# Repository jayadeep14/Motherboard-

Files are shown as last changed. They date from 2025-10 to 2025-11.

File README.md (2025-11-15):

# Motherboard - aizeronix
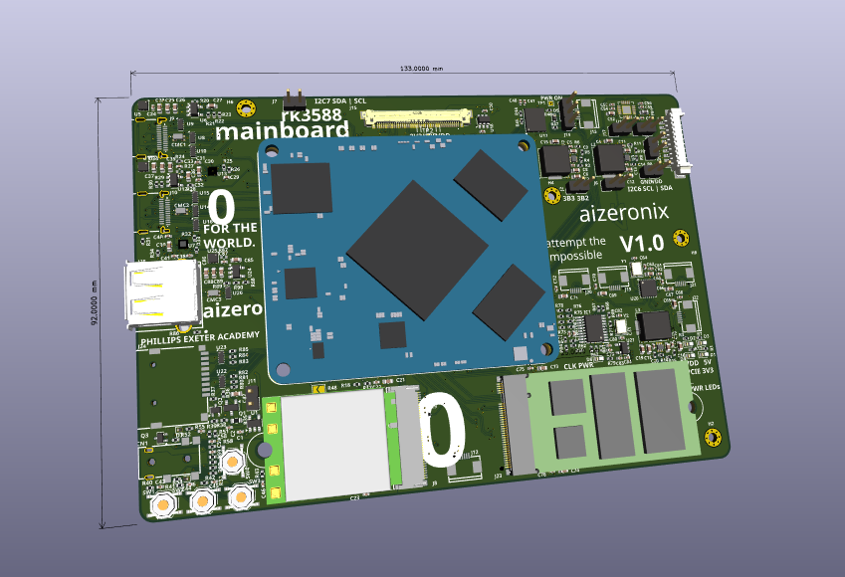
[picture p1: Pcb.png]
Pcb

This project focuses on the design and development of a custom motherboard using a rk3588. The goal is to create a compact, high-performance solution tailored for embedded systems and other specialized applications. The motherboard will feature a variety of interfaces for connectivity, expansion, and power management, all while leveraging Rockchip’s powerful processor architecture.  

Project Objectives

The project had both technical and design objectives:

Design a functional schematic of a custom RK3588 motherboard with essential peripherals and expansion options.

Develop a compact PCB layout, ensuring signal integrity, power stability, and thermal management.

Integrate various interfaces, including USB, Ethernet, MIPI camera inputs, HDMI outputs, and PCIe expansion.

Design a robust power management system, capable of handling multiple voltage rails efficiently.

Prototype and test the motherboard for functionality, stability, and performance

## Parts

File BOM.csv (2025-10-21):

JLCPCB BOM Tool - BOM Matching
BOM name：motherboard-JLCPCB Assembly Order.xlsx |  |  | Download Time：2025-10-21 23:37:49 |  |  |  | * Our matching results are updated in real-time, but stock and prices may change. If it's been over 24 hours, please re-match before placing your order.
PCB Assembled Qty：5 |  |  | Est. Total Price：95.7691
Your BOM |  |  |  |  | Matched Parts |  |  |  |  |  |  | Order Information
Top Designator | Bottom Designator | Comment | Footprint | JLCPCB Part # | Matches | Part # | Manufacturer | Footprint | Description | Category | Warning | JLCPCB Part # | Product link | Lib Type | Qty | Source | Total Price ($)
C30,C60,C65,C86,C28,C52,C42,C3,C16,C27,C4,C10,C37,C9,C67,C36,C71,C39,C15,C69,C85 |  | 10uF | C_0603_1608Metric |  | Unconfirmed | CL10A106KP8NNNC | Samsung Electro-Mechanics | 603 | 10V 10uF X5R ±10% 0603 Multilayer Ceramic Capacitors MLCC - SMD/SMT ROHS | Multilayer Ceramic Capacitors MLCC - SMD/SMT | 1.Multiple lines in the BOM have been matched to the same part. Please check if the matching is correct. ; | C19702 | https://jlcpcb.com/partdetail/20411-CL10A106KP8NNNC/C19702 | Basic | 145 | 145 JLCPCB | 0.812
C88,C26,C25,C35,C34,C89 |  | 10uF(C913517) | C_0603_1608Metric |  | Unconfirmed | CL10A106KP8NNNC | Samsung Electro-Mechanics | 603 | 10V 10uF X5R ±10% 0603 Multilayer Ceramic Capacitors MLCC - SMD/SMT ROHS | Multilayer Ceramic Capacitors MLCC - SMD/SMT | 1.Multiple lines in the BOM have been matched to the same part. Please check if the matching is correct. ; | C19702 | https://jlcpcb.com/partdetail/20411-CL10A106KP8NNNC/C19702 | Basic | 145 | 145 JLCPCB | 0.812
C33,C24,C87 |  | 100nF(+25V) | C_0402_1005Metric |  | Select by Customer | 0402B104K250NT | FH (Guangdong Fenghua Advanced Tech) | 402 | 100nF 25V X7R ±10% 0402 Multilayer Ceramic Capacitors MLCC - SMD/SMT ROHS | Multilayer Ceramic Capacitors MLCC - SMD/SMT |  | C56392 | https://jlcpcb.com/partdetail/57421-0402B104K250NT/C56392 | Extended | 27 | 27 JLCPCB | 0.0324
C41,C40,C32,C31 |  | 220pF | C_0402_1005Metric |  | Select by System | CL02B221KP2NNNC | Samsung Electro-Mechanics | 1005 | 10V 220pF X7R ±10% 01005 Multilayer Ceramic Capacitors MLCC - SMD/SMT ROHS | Multilayer Ceramic Capacitors MLCC - SMD/SMT |  | C514578 | https://jlcpcb.com/partdetail/530300-CL02B221KP2NNNC/C514578 | Extended | 40 | 40 JLCPCB | 0.252
C43,C46,C44,C45 |  | 1nF | C_0402_1005Metric |  | Select by System | GRM022R71C102KE14D | Murata Electronics | 1005 | 16V 1nF ±10% 01005 Multilayer Ceramic Capacitors MLCC - SMD/SMT ROHS | Multilayer Ceramic Capacitors MLCC - SMD/SMT |  | C907725 | https://jlcpcb.com/partdetail/973775-GRM022R71C102KE14D/C907725 | Extended | 40 | 40 JLCPCB | 0.264
C51,C68,C76,C70,C72,C66,C23,C61,C59,C58,C47 |  | 0.1uF | C_0402_1005Metric |  | Unconfirmed | GRM022R60J104KE15D | Murata Electronics | 1005 | 100nF 6.3V X5R ±10% 01005 Multilayer Ceramic Capacitors MLCC - SMD/SMT ROHS | Multilayer Ceramic Capacitors MLCC - SMD/SMT | 1.The comment (GRM022R60J104KE15D) of this part does not match the one (0.1uF) provided in your BOM. Please confirm; 2.Multiple lines in the BOM have been matched to the same part. Please check if the matching is correct. ; | C161362 | https://jlcpcb.com/partdetail/172743-GRM022R60J104KE15D/C161362 | Extended | 120 | 120 JLCPCB | 0.312
C80,C11,C14,C29,C38,C8,C78,C20,C5,C17 |  | 100nF | C_0402_1005Metric |  | Unconfirmed | GRM022R60J104KE15D | Murata Electronics | 1005 | 100nF 6.3V X5R ±10% 01005 Multilayer Ceramic Capacitors MLCC - SMD/SMT ROHS | Multilayer Ceramic Capacitors MLCC - SMD/SMT | 1.Multiple lines in the BOM have been matched to the same part. Please check if the matching is correct. ; | C161362 | https://jlcpcb.com/partdetail/172743-GRM022R60J104KE15D/C161362 | Extended | 120 | 120 JLCPCB | 0.312
C64,C63,C81,C82 |  | 15pF | C_0402_1005Metric |  | Select by Customer | 0402CG150J500NT | FH (Guangdong Fenghua Advanced Tech) | 402 | 15pF 50V C0G ±5% 0402 Multilayer Ceramic Capacitors MLCC - SMD/SMT ROHS | Multilayer Ceramic Capacitors MLCC - SMD/SMT |  | C1548 | https://jlcpcb.com/partdetail/1900-0402CG150J500NT/C1548 | Basic | 30 | 30 JLCPCB | 0.03
C74,C6,C13,C21,C7,C18,C19,C12,C73 |  | 22uF | C_0603_1608Metric |  | Select by System | CL10A226MQ8NRNC | Samsung Electro-Mechanics | 603 | 22uF 6.3V X5R ±20% 0603 Multilayer Ceramic Capacitors MLCC - SMD/SMT ROHS | Multilayer Ceramic Capacitors MLCC - SMD/SMT |  | C59461 | https://jlcpcb.com/partdetail/60514-CL10A226MQ8NRNC/C59461 | Basic | 55 | 55 JLCPCB | 0.4785
C84,C83,C48,C49,C53,C2,C57,C77,C22,C79,C50,C75,C62,C56,C1,C55,C54 |  | 1uF | C_0402_1005Metric |  | Select by Customer | GRM155R60J105KE19D | Murata Electronics | 402 | 1uF 6.3V X5R ±10% 0402 Multilayer Ceramic Capacitors MLCC - SMD/SMT ROHS | Multilayer Ceramic Capacitors MLCC - SMD/SMT |  | C15684 | https://jlcpcb.com/partdetail/MurataElectronics-GRM155R60J105KE19D/C15684 | Extended | 95 | 95 JLCPCB | 0.266
CMC3,CMC2,CMC1 |  | ACM2012 | FIL_ACM2012-900-2P-T001 |  | Select by System | ACM2012-121-2P-T002 | TDK | SMD-4P | -40℃~+85℃ 120Ω@100MHz 2 220mΩ 370mA 50V SMD-4P Common Mode Filters ROHS | Common Mode Filters |  | C76571 | https://jlcpcb.com/partdetail/TDK-ACM2012_121_2PT002/C76571 | Extended | 17 | 17 JLCPCB | 1.666
CN1 |  | PJ-332A-6A(3.5mmJack) | AUDIO-SMD_PJ-332A-6A |  | Unconfirmed | PJ-332A-6A | Korean Hroparts Elec | SMD | -25℃~+80℃ 1A 3.5mm Headphone Jack 30V SMD Audio Connectors ROHS | Audio Connectors (Headphones) | 1.The comment (PJ-332A-6A) of this part does not match the one (PJ-332A-6A(3.5mmJack)) provided in your BOM. Please confirm; | C2848643 | https://jlcpcb.com/partdetail/Korean_HropartsElec-PJ_332A6A/C2848643 | Extended | 5 | 5 JLCPCB | 1.186
D1 |  | +3.3VLED | LED_0603_1608Metric |  | Unconfirmed | KT-0603R | Hubei KENTO Elec | 603 | -40℃~+85℃ 120° 2.4V 20mA 300mcd 40mW 615nm~630nm 645nm Red Water Clear 0603 LED Indication - Discrete ROHS | LED Indication - Discrete | 1.The comment (KT-0603R) of this part does not match the one (+3.3VLED) provided in your BOM. Please confirm; 2.Multiple lines in the BOM have been matched to the same part. Please check if the matching is correct. ; | C2286 | https://jlcpcb.com/partdetail/Hubei_KENTOElec-KT0603R/C2286 | Basic | 35 | 35 JLCPCB | 0.196
D2 |  | VDDLED | LED_0603_1608Metric |  | Unconfirmed | KT-0603R | Hubei KENTO Elec | 603 | -40℃~+85℃ 120° 2.4V 20mA 300mcd 40mW 615nm~630nm 645nm Red Water Clear 0603 LED Indication - Discrete ROHS | LED Indication - Discrete | 1.The comment (KT-0603R) of this part does not match the one (VDDLED) provided in your BOM. Please confirm; 2.Multiple lines in the BOM have been matched to the same part. Please check if the matching is correct. ; | C2286 | https://jlcpcb.com/partdetail/Hubei_KENTOElec-KT0603R/C2286 | Basic | 35 | 35 JLCPCB | 0.196
D3 |  | +5VLED | LED_0603_1608Metric |  | Unconfirmed | KT-0603R | Hubei KENTO Elec | 603 | -40℃~+85℃ 120° 2.4V 20mA 300mcd 40mW 615nm~630nm 645nm Red Water Clear 0603 LED Indication - Discrete ROHS | LED Indication - Discrete | 1.The comment (KT-0603R) of this part does not match the one (+5VLED) provided in your BOM. Please confirm; 2.Multiple lines in the BOM have been matched to the same part. Please check if the matching is correct. ; | C2286 | https://jlcpcb.com/partdetail/Hubei_KENTOElec-KT0603R/C2286 | Basic | 35 | 35 JLCPCB | 0.196
D4 |  | PCIELED | LED_0603_1608Metric |  | Unconfirmed | KT-0603R | Hubei KENTO Elec | 603 | -40℃~+85℃ 120° 2.4V 20mA 300mcd 40mW 615nm~630nm 645nm Red Water Clear 0603 LED Indication - Discrete ROHS | LED Indication - Discrete | 1.The comment (KT-0603R) of this part does not match the one (PCIELED) provided in your BOM. Please confirm; 2.Multiple lines in the BOM have been matched to the same part. Please check if the matching is correct. ; | C2286 | https://jlcpcb.com/partdetail/Hubei_KENTOElec-KT0603R/C2286 | Basic | 35 | 35 JLCPCB | 0.196
D8 |  | PI6CLED | LED_0603_1608Metric |  | Unconfirmed | KT-0603R | Hubei KENTO Elec | 603 | -40℃~+85℃ 120° 2.4V 20mA 300mcd 40mW 615nm~630nm 645nm Red Water Clear 0603 LED Indication - Discrete ROHS | LED Indication - Discrete | 1.The comment (KT-0603R) of this part does not match the one (PI6CLED) provided in your BOM. Please confirm; 2.Multiple lines in the BOM have been matched to the same part. Please check if the matching is correct. ; | C2286 | https://jlcpcb.com/partdetail/Hubei_KENTOElec-KT0603R/C2286 | Basic | 35 | 35 JLCPCB | 0.196
D5 |  | LRB521S-30T1G | D_SOD-523 |  | Select by System | LRB521S-30T1G | LRC | SOD-523 | -40℃~+125℃ 1A 200mA 30V 30uA 500mV SOD-523 Schottky Diodes ROHS | Schottky Diodes |  | C83681 | https://jlcpcb.com/partdetail/LRC-LRB521S30T1G/C83681 | Extended | 20 | 20 JLCPCB | 0.284
D6,D7 |  | LESD8D5.0CB1T5G | D_SOD-882 |  | Select by System | LESD8D5.0CB1T5G | LRC | SOD-882 | -40℃~+150℃ 10A@8/20us 20pF 500nA 5V 85W@8/20us 8V 9V ESD SOD-882 ESD and Surge Protection (TVS/ESD) ROHS | ESD And Surge Protection (TVS/ESD) |  | C2936709 | https://jlcpcb.com/partdetail/LRC-LESD8D50CB1T5G/C2936709 | Extended | 20 | 20 JLCPCB | 0.176
FB1 |  | GZ1608D601TF | L_0603_1608Metric |  | Select by System | GZ1608D601TF | Sunlord | 603 | -55℃~+125℃ 1 200mA 450mΩ 600Ω@100MHz ±25% 0603 Ferrite Beads ROHS | Ferrite Beads |  | C1002 | https://jlcpcb.com/partdetail/Sunlord-GZ1608D601TF/C1002 | Basic | 20 | 20 JLCPCB | 0.132
H3,H5,H1,H7 |  | Hirose | Blank |  | Select by Customer | DF40C-100DS-0.4V(51) | HRS(Hirose) | SMD,P=0.4mm | -35℃~+85℃ 0.4mm 2 300mA Gold Surface Mount,Vertical SMD,P=0.4mm Board-to-Board and Backplane Connector ROHS | Board-To-Board And Backplane Connector |  | C597931 | https://jlcpcb.com/partdetail/HRS_Hirose-DF40C_100DS_0_4V_51/C597931 | Extended | 20 | 20 JLCPCB | 14.49
IC1 |  | PI6C557-05BLE | SOP65P640X120-20N |  | Select by System | PI6C557-05BLE | Diodes Incorporated | TSSOP-20 | -40℃~+85℃ 200MHz 3.135V~3.465V 4 TSSOP-20 Clock Generators, PLLs, Frequency Synthesizers ROHS | Clock Generators, PLLs, Frequency Synthesizers |  | C212303 | https://jlcpcb.com/partdetail/DiodesIncorporated-PI6C55705BLE/C212303 | Extended | 5 | 5 JLCPCB | 7.545
J4 |  | BATTERYIN | Molex_PicoBlade_53261-1071_1x10-1MP_P1.25mm_Horizontal |  | Select by Customer | 532611071 | MOLEX | SMD,P=1.25mm,卧贴 | -40℃~+105℃ 1 1.25mm 10 10P 125V 17.65mm 1A 1x10P 3.4mm 5.2mm Auxiliary Solder Pin Glass-Fiber Reinforced PA Phosphor Bronze PicoBlade(MX 1.25) Surface Mount, Right Angle Tin UL94V-0 White SMD,P=1.25mm,Surface Mount，Right Angle Wire To Board Connector ROHS | Wire To Board Connector |  | C564042 | https://jlcpcb.com/partdetail/MOLEX-532611071/C564042 | Extended | 5 | 5 JLCPCB | 1.14
J8 |  | Bus_M.2_Socket_E | CONN-SMD_APCI0147-P001A |  | Unconfirmed | APCI0147-P001A | LOTES | SMD,P=0.5mm,卧贴 | 2.05mm 67P Female M.2-E Key Surface Mount, Right Angle with locating pin SMD,P=0.5mm,Surface Mount，Right Angle Hard Disk Connector (SAS/SATA/M.2) ROHS | Edgeboard Connectors | 1.The comment (APCI0147-P001A) of this part does not match the one (Bus_M.2_Socket_E) provided in your BOM. Please confirm; | C841646 | https://jlcpcb.com/partdetail/LOTES-APCI0147P001A/C841646 | Extended | 5 | 5 JLCPCB | 3.015
J9 |  | OuterUSB-C | USB-C-SMD_TYPE-C-24P-QT |  | Unconfirmed | TYPE-C 24P QT | SHOU HAN | SMD | -30℃~+80℃ 1 10,000 Cycles 24P 3A Black Female Surface Mount, Right Angle Type-C USB 3.1 SMD USB Connectors ROHS | USB Connectors | 1.The comment (TYPE-C 24P QT) of this part does not match the one (OuterUSB-C) provided in your BOM. Please confirm; 2.Multiple lines in the BOM have been matched to the same part. Please check if the matching is correct. ; | C2681555 | https://jlcpcb.com/partdetail/SHOUHAN-TYPE_C_24PQT/C2681555 | Extended | 10 | 10 JLCPCB | 4.725
J10 |  | USB_C_Receptacle | USB-C-SMD_TYPE-C-24P-QT |  | Unconfirmed | TYPE-C 24P QT | SHOU HAN | SMD | -30℃~+80℃ 1 10,000 Cycles 24P 3A Black Female Surface Mount, Right Angle Type-C USB 3.1 SMD USB Connectors ROHS | USB Connectors | 1.The comment (TYPE-C 24P QT) of this part does not match the one (USB_C_Receptacle) provided in your BOM. Please confirm; 2.Multiple lines in the BOM have been matched to the same part. Please check if the matching is correct. ; | C2681555 | https://jlcpcb.com/partdetail/SHOUHAN-TYPE_C_24PQT/C2681555 | Extended | 10 | 10 JLCPCB | 4.725
J12 |  | HALLSWITCH | FPC-SMD_6P-P0.50_XUNPU_FPC-05F-6PH20 |  | Unconfirmed | FPC-05F-6PH20 | XUNPU | SMD,P=0.5mm,卧贴 | -25℃~+85℃ 0.3mm 0.5mm 2mm 500mA 50V 6P Bottom Contact Hinged Lid Phosphor Bronze Surface Mount, Right Angle Tin SMD,P=0.5mm,Surface Mount，Right Angle FFC, FPC (Flat Flexible) Connector Assemblies ROHS | FFC, FPC (Flat Flexible) Connector Assemblies | 1.The comment (FPC-05F-6PH20) of this part does not match the one (HALLSWITCH) provided in your BOM. Please confirm; 2.Multiple lines in the BOM have been matched to the same part. Please check if the matching is correct. ; | C2856796 | https://jlcpcb.com/partdetail/XUNPU-FPC_05F6PH20/C2856796 | Extended | 32 | 32 JLCPCB | 2.6368
J13 |  | SYSTEM | FPC-SMD_6P-P0.50_XUNPU_FPC-05F-6PH20 |  | Unconfirmed | FPC-05F-6PH20 | XUNPU | SMD,P=0.5mm,卧贴 | -25℃~+85℃ 0.3mm 0.5mm 2mm 500mA 50V 6P Bottom Contact Hinged Lid Phosphor Bronze Surface Mount, Right Angle Tin SMD,P=0.5mm,Surface Mount，Right Angle FFC, FPC (Flat Flexible) Connector Assemblies ROHS | FFC, FPC (Flat Flexible) Connector Assemblies | 1.The comment (FPC-05F-6PH20) of this part does not match the one (SYSTEM) provided in your BOM. Please confirm; 2.Multiple lines in the BOM have been matched to the same part. Please check if the matching is correct. ; | C2856796 | https://jlcpcb.com/partdetail/XUNPU-FPC_05F6PH20/C2856796 | Extended | 32 | 32 JLCPCB | 2.6368
J20,J19,J21,J22 |  | USB | FPC-SMD_6P-P0.50_XUNPU_FPC-05F-6PH20 |  | Unconfirmed | FPC-05F-6PH20 | XUNPU | SMD,P=0.5mm,卧贴 | -25℃~+85℃ 0.3mm 0.5mm 2mm 500mA 50V 6P Bottom Contact Hinged Lid Phosphor Bronze Surface Mount, Right Angle Tin SMD,P=0.5mm,Surface Mount，Right Angle FFC, FPC (Flat Flexible) Connector Assemblies ROHS | FFC, FPC (Flat Flexible) Connector Assemblies | 1.The comment (FPC-05F-6PH20) of this part does not match the one (USB) provided in your BOM. Please confirm; 2.Multiple lines in the BOM have been matched to the same part. Please check if the matching is correct. ; | C2856796 | https://jlcpcb.com/partdetail/XUNPU-FPC_05F6PH20/C2856796 | Extended | 32 | 32 JLCPCB | 2.6368
J23 |  | Bus_M.2_Socket_M | CONN-SMD_AS0BC21-S30BM-7H |  | Unconfirmed | AS0BC21-S30BM-7H | FOXCONN | SMD,P=0.5mm,卧贴 | -40℃~+80℃ 67P Female M.2-M Key Surface Mount, Right Angle with locating pin SMD,P=0.5mm,Surface Mount，Right Angle Hard Disk Connector (SAS/SATA/M.2) ROHS | Edgeboard Connectors | 1.The comment (AS0BC21-S30BM-7H) of this part does not match the one (Bus_M.2_Socket_M) provided in your BOM. Please confirm; | C2832351 | https://jlcpcb.com/partdetail/FOXCONN-AS0BC21_S30BM7H/C2832351 | Extended | 5 | 5 JLCPCB | 1.6465
J24 |  | Micro_SD_Card_Det1 | TF-SMD_TF-CARD-H1.8 |  | Unconfirmed | TF-CARD H1.8 | SHOU HAN | SMD | -40℃~+70℃ 1.8mm Connector and Ejector MicroSD Card (TF Card) Push-Push SMD SD Card / Memory Card Connector ROHS | SD Card / Memory Card Connector | 1.The comment (TF-CARD H1.8) of this part does not match the one (Micro_SD_Card_Det1) provided in your BOM. Please confirm; | C7529389 | https://jlcpcb.com/partdetail/SHOUHAN-TF_CARD_H18/C7529389 | Extended | 5 | 5 JLCPCB | 0.2845
J25 |  | USB-231-ARY | USB-A-TH_USB-231-ARY |  | Select by System | USB-231-ARY | XUNPU | 弯插 | -20℃~+70℃ 1 1.5A 14.2mm 30V 4P Female Right Angle Type-A USB 2.0 White Push-Pull USB Connectors ROHS | USB Connectors |  | C720525 | https://jlcpcb.com/partdetail/XUNPU-USB_231ARY/C720525 | Extended | 5 | 5 JLCPCB | 0.6685
L1,L3 |  | MWSA0603S-3R3MT | L_Sunlord_MWSA0603S |  | Select by System | MWSA0603S-3R3MT | Sunlord | SMD,7x6.6mm | 22mΩ 3.3uH 8.5A 9.5A ±20% SMD,7x6.6mm Power Inductors ROHS | Power Inductors |  | C408446 | https://jlcpcb.com/partdetail/Sunlord-MWSA0603S3R3MT/C408446 | Extended | 11 | 11 JLCPCB | 1.2474
L2 |  | FXL0630-4R7-M | L_Sunlord_MWSA0603S |  | Select by System | FXL0630-4R7-M | cjiang (Changjiang Microelectronics Tech) | SMD,7x6.6mm | 33mΩ 4.7uH 6A 9A Molded Inductor ±20% SMD,7x6.6mm Power Inductors ROHS | Power Inductors |  | C167220 | https://jlcpcb.com/partdetail/178603-FXL0630_4R7M/C167220 | Extended | 6 | 6 JLCPCB | 0.5196
Q1 |  | AO3415A | SOT-23 |  | Select by System | AO3415A | UMW(Youtai Semiconductor Co., Ltd.) | SOT-23 | -55℃~+150℃ 1 P-Channel 1.45nF 160pF 17.2nC@4.5V 205pF 20V 350mW 36mΩ@4.5V 4A 560mV@250uA N-Channel SOT-23 MOSFETs ROHS | MOSFETs |  | C347479 | https://jlcpcb.com/partdetail/324139-AO3415A/C347479 | Extended | 9 | 9 JLCPCB | 0.3321
Q3,Q2 |  | 2SK3018W | SOT-323_SC-70 |  | Select by System | 2SK3018W | TWGMC | SOT-323 | -55℃~+150℃ 1 N-Channel 1.5V 100mA 13pF 13Ω@2.5V,1mA 200mW 30V 4pF 9pF SOT-323 MOSFETs ROHS | MOSFETs |  | C5273793 | https://jlcpcb.com/partdetail/TWGMC-2SK3018W/C5273793 | Extended | 15 | 15 JLCPCB | 0.243
R5,R15 |  | 510k | R_0402_1005Metric |  | Unconfirmed | 0105WHJ0514TDE | UNI-ROYAL(Uniroyal Elec) | 1005 | -55℃~+125℃ 15V 31.25mW 510kΩ Thick Film Resistor ±200ppm/℃ ±5% 01005 Chip Resistor - Surface Mount ROHS | Chip Resistor - Surface Mount | 1.The comment (0105WHJ0514TDE) of this part does not match the one (510k) provided in your BOM. Please confirm; | C270295 | https://jlcpcb.com/partdetail/259825-0105WHJ0514TDE/C270295 | Extended | 40 | 40 JLCPCB | 0.184
R9 |  | 220k | R_0402_1005Metric |  | Unconfirmed | 0105WHF2203TDE | UNI-ROYAL(Uniroyal Elec) | 1005 | -55℃~+125℃ 15V 220kΩ 31.25mW Thick Film Resistor ±1% ±200ppm/℃ 01005 Chip Resistor - Surface Mount ROHS | Chip Resistor - Surface Mount | 1.The comment (0105WHF2203TDE) of this part does not match the one (220k) provided in your BOM. Please confirm; | C473646 | https://jlcpcb.com/partdetail/480039-0105WHF2203TDE/C473646 | Extended | 40 | 40 JLCPCB | 0.264
R10 |  | 330k | R_0402_1005Metric |  | Unconfirmed | 0105WHF3303TDE | UNI-ROYAL(Uniroyal Elec) | 1005 | -55℃~+125℃ 15V 31.25mW 330kΩ Thick Film Resistor ±1% ±200ppm/℃ 01005 Chip Resistor - Surface Mount ROHS | Chip Resistor - Surface Mount | 1.The comment (0105WHF3303TDE) of this part does not match the one (330k) provided in your BOM. Please confirm; | C778410 | https://jlcpcb.com/partdetail/827054-0105WHF3303TDE/C778410 | Extended | 20 | 20 JLCPCB | 0.06
R14,R4 |  | 49.9k | R_0402_1005Metric |  | Unconfirmed | RC0100FR-0749K9L | YAGEO | 1005 | -55℃~+125℃ 15V 31.25mW 49.9kΩ Thick Film Resistor ±1% ±200ppm/℃ 01005 Chip Resistor - Surface Mount ROHS | Chip Resistor - Surface Mount | 1.The comment (RC0100FR-0749K9L) of this part does not match the one (49.9k) provided in your BOM. Please confirm; | C850275 | https://jlcpcb.com/partdetail/YAGEO-RC0100FR0749K9L/C850275 | Extended | 40 | 40 JLCPCB | 0.108
R28,R88,R21,R51 |  | 100k | R_0402_1005Metric |  | Unconfirmed | RC0100FR-07100KL | YAGEO | 1005 | -55℃~+125℃ 100kΩ 15V 31.25mW Thick Film Resistor ±1% ±200ppm/℃ 01005 Chip Resistor - Surface Mount ROHS | Chip Resistor - Surface Mount | 1.The comment (RC0100FR-07100KL) of this part does not match the one (100k) provided in your BOM. Please confirm; | C723496 | https://jlcpcb.com/partdetail/YAGEO-RC0100FR07100KL/C723496 | Extended | 40 | 40 JLCPCB | 0.108
R31,R86,R24 |  | 1M | R_0402_1005Metric |  | Unconfirmed | MCR004YZPJ105 | ROHM Semicon | 1005 | -55℃~+125℃ 15V 1MΩ 31mW Thick Film Resistor ±250ppm/℃ ±5% 01005 Chip Resistor - Surface Mount ROHS | Chip Resistor - Surface Mount | 1.The comment (MCR004YZPJ105) of this part does not match the one (1M) provided in your BOM. Please confirm; | C307987 | https://jlcpcb.com/partdetail/ROHMSemicon-MCR004YZPJ105/C307987 | Extended | 40 | 40 JLCPCB | 0.252
R33,R25,R32,R26,R50,R19 |  | 2.2k | R_0402_1005Metric |  | Unconfirmed | RC0100JR-072K2L | YAGEO | 1005 | -55℃~+125℃ 15V 2.2kΩ 31.25mW Thick Film Resistor ±200ppm/℃ ±5% 01005 Chip Resistor - Surface Mount ROHS | Chip Resistor - Surface Mount | 1.The comment (RC0100JR-072K2L) of this part does not match the one (2.2k) provided in your BOM. Please confirm; | C723377 | https://jlcpcb.com/partdetail/YAGEO-RC0100JR072K2L/C723377 | Extended | 45 | 45 JLCPCB | 0.099
R35 |  | 2.2R | R_0603_1608Metric |  | Unconfirmed | 0603WAF220KT5E | UNI-ROYAL(Uniroyal Elec) | 603 | -55℃~+155℃ 100mW 2.2Ω 75V Thick Film Resistor ±1% ±400ppm/℃ 0603 Chip Resistor - Surface Mount ROHS | Chip Resistor - Surface Mount | 1.The comment (0603WAF220KT5E) of this part does not match the one (2.2R) provided in your BOM. Please confirm; | C22939 | https://jlcpcb.com/partdetail/23666-0603WAF220KT5E/C22939 | Basic | 20 | 20 JLCPCB | 0.032
R37 |  | 1k | R_0402_1005Metric |  | Unconfirmed | 0105WHJ0102TDE | UNI-ROYAL(Uniroyal Elec) | 1005 | -55℃~+125℃ 15V 1kΩ 31.25mW Thick Film Resistor ±200ppm/℃ ±5% 01005 Chip Resistor - Surface Mount ROHS | Chip Resistor - Surface Mount | 1.The comment (0105WHJ0102TDE) of this part does not match the one (1k) provided in your BOM. Please confirm; | C407788 | https://jlcpcb.com/partdetail/396345-0105WHJ0102TDE/C407788 | Extended | 40 | 40 JLCPCB | 0.216
R39,R43,R41,R40,R71,R42 |  | 100R | R_0402_1005Metric |  | Unconfirmed | 0105WHJ0101TDE | UNI-ROYAL(Uniroyal Elec) | 1005 | -55℃~+125℃ 100Ω 15V 31.25mW Thick Film Resistor ±400ppm/℃ ±5% 01005 Chip Resistor - Surface Mount ROHS | Chip Resistor - Surface Mount | 1.The comment (0105WHJ0101TDE) of this part does not match the one (100R) provided in your BOM. Please confirm; | C270299 | https://jlcpcb.com/partdetail/259829-0105WHJ0101TDE/C270299 | Extended | 45 | 45 JLCPCB | 0.2385
R52,R57,R7,R8,R1,R12,R67,R16,R44,R13,R46,R45,R68,R2,R6,R56,R38,R34 |  | 10k | R_0402_1005Metric |  | Unconfirmed | 0105WHJ0103TDE | UNI-ROYAL(Uniroyal Elec) | 1005 | -55℃~+125℃ 10kΩ 15V 31.25mW Thick Film Resistor ±200ppm/℃ ±5% 01005 Chip Resistor - Surface Mount ROHS | Chip Resistor - Surface Mount | 1.The comment (0105WHJ0103TDE) of this part does not match the one (10k) provided in your BOM. Please confirm; | C407787 | https://jlcpcb.com/partdetail/396344-0105WHJ0103TDE/C407787 | Extended | 105 | 105 JLCPCB | 0.567
R63,R17,R55,R61,R54,R87,R20,R27,R53,R18 |  | 0R | R_0402_1005Metric |  | Unconfirmed | RC0100FR-070RL | YAGEO | 1005 | -55℃~+125℃ 0Ω 15V 31.25mW Thick Film Resistor ±1% 01005 Chip Resistor - Surface Mount ROHS | Chip Resistor - Surface Mount | 1.The comment (RC0100FR-070RL) of this part does not match the one (0R) provided in your BOM. Please confirm; | C2936587 | https://jlcpcb.com/partdetail/YAGEO-RC0100FR070RL/C2936587 | Extended | 65 | 65 JLCPCB | 0.2535
R66 |  | 4.7k | R_0402_1005Metric |  | Unconfirmed | 0105WHJ0472TDE | UNI-ROYAL(Uniroyal Elec) | 1005 | -55℃~+125℃ 15V 31.25mW 4.7kΩ Thick Film Resistor ±200ppm/℃ ±5% 01005 Chip Resistor - Surface Mount ROHS | Chip Resistor - Surface Mount | 1.The comment (0105WHJ0472TDE) of this part does not match the one (4.7k) provided in your BOM. Please confirm; | C423829 | https://jlcpcb.com/partdetail/416779-0105WHJ0472TDE/C423829 | Extended | 40 | 40 JLCPCB | 0.228
R69,R36 |  | 470R | R_0402_1005Metric |  | Select by Customer | 0402WGF4700TCE | UNI-ROYAL(Uniroyal Elec) | 402 | -55℃~+155℃ 470Ω 50V 62.5mW Thick Film Resistor ±1% ±100ppm/℃ 0402 Chip Resistor - Surface Mount ROHS | Chip Resistor - Surface Mount | 1.The comment (0402WGF4700TCE) of this part does not match the one (470R) provided in your BOM. Please confirm; | C25117 | https://jlcpcb.com/partdetail/25860-0402WGF4700TCE/C25117 | Basic | 20 | 20 JLCPCB | 0.012
R72,R85,R62,R60,R76,R58,R80,R82,R81,R84,R70,R59,R83,R75,R47 |  | 33R | R_0402_1005Metric |  | Select by Customer | 0402WGF330JTCE | UNI-ROYAL(Uniroyal Elec) | 402 | -55℃~+155℃ 33Ω 50V 62.5mW Thick Film Resistor ±1% ±100ppm/℃ 0402 Chip Resistor - Surface Mount ROHS | Chip Resistor - Surface Mount | 1.The comment (0402WGF330JTCE) of this part does not match the one (33R) provided in your BOM. Please confirm; | C25105 | https://jlcpcb.com/partdetail/25848-0402WGF330JTCE/C25105 | Basic | 85 | 85 JLCPCB | 0.051
R73,R64,R74,R77,R78,R65 |  | 49.9R | R_0402_1005Metric |  | Unconfirmed | 0105WHF499JTDE | UNI-ROYAL(Uniroyal Elec) | 1005 | -55℃~+125℃ 15V 31.25mW 49.9Ω Thick Film Resistor ±1% ±300ppm/℃ 01005 Chip Resistor - Surface Mount ROHS | Chip Resistor - Surface Mount | 1.The comment (0105WHF499JTDE) of this part does not match the one (49.9R) provided in your BOM. Please confirm; | C560373 | https://jlcpcb.com/partdetail/584835-0105WHF499JTDE/C560373 | Extended | 45 | 45 JLCPCB | 0.351
R79,R11,R3 |  | 33k | R_0402_1005Metric |  | Unconfirmed | 0105WHF3302TDE | UNI-ROYAL(Uniroyal Elec) | 1005 | -55℃~+125℃ 15V 31.25mW 33kΩ Thick Film Resistor ±1% ±200ppm/℃ 01005 Chip Resistor - Surface Mount ROHS | Chip Resistor - Surface Mount | 1.The comment (0105WHF3302TDE) of this part does not match the one (33k) provided in your BOM. Please confirm; | C560356 | https://jlcpcb.com/partdetail/584818-0105WHF3302TDE/C560356 | Extended | 40 | 40 JLCPCB | 0.26
R90,R89,R23,R29,R30,R22 |  | 6.8k | R_0402_1005Metric |  | Select by Customer | 0402WGF6801TCE | UNI-ROYAL(Uniroyal Elec) | 402 | -55℃~+155℃ 50V 6.8kΩ 62.5mW Thick Film Resistor ±1% ±100ppm/℃ 0402 Chip Resistor - Surface Mount ROHS | Chip Resistor - Surface Mount | 1.The comment (0402WGF6801TCE) of this part does not match the one (6.8k) provided in your BOM. Please confirm; | C25917 | https://jlcpcb.com/partdetail/26660-0402WGF6801TCE/C25917 | Extended | 40 | 40 JLCPCB | 0.024
SW1 |  | PWR | SW_Push_1P1T_XKB_TS-1187A |  | Select by Customer | TS-1187A-B-A-B | XKB Connection | SMD-4P,5.1x5.1mm | -30℃~+85℃ 1.5mm 1.6N 100,000 Cycles 12V 5.1mm 5.1mm 50mA Gold No Round Button SPST Surface Mount,Vertical Without Bracket SMD-4P,5.1x5.1mm Tactile Switches ROHS | Tactile Switches | 1.Multiple lines in the BOM have been matched to the same part. Please check if the matching is correct. ; | C318884 | https://jlcpcb.com/partdetail/XKBConnection-TS_1187A_B_AB/C318884 | Basic | 25 | 25 JLCPCB | 0.465
SW2 |  | RESET | SW_Push_1P1T_XKB_TS-1187A |  | Select by Customer | TS-1187A-B-A-B | XKB Connection | SMD-4P,5.1x5.1mm | -30℃~+85℃ 1.5mm 1.6N 100,000 Cycles 12V 5.1mm 5.1mm 50mA Gold No Round Button SPST Surface Mount,Vertical Without Bracket SMD-4P,5.1x5.1mm Tactile Switches ROHS | Tactile Switches | 1.The comment (TS-1187A-B-A-B) of this part does not match the one (RESET) provided in your BOM. Please confirm; 2.Multiple lines in the BOM have been matched to the same part. Please check if the matching is correct. ; | C318884 | https://jlcpcb.com/partdetail/XKBConnection-TS_1187A_B_AB/C318884 | Basic | 25 | 25 JLCPCB | 0.465
SW3 |  | MASK | SW_Push_1P1T_XKB_TS-1187A |  | Select by Customer | TS-1187A-B-A-B | XKB Connection | SMD-4P,5.1x5.1mm | -30℃~+85℃ 1.5mm 1.6N 100,000 Cycles 12V 5.1mm 5.1mm 50mA Gold No Round Button SPST Surface Mount,Vertical Without Bracket SMD-4P,5.1x5.1mm Tactile Switches ROHS | Tactile Switches | 1.Multiple lines in the BOM have been matched to the same part. Please check if the matching is correct. ; | C318884 | https://jlcpcb.com/partdetail/XKBConnection-TS_1187A_B_AB/C318884 | Basic | 25 | 25 JLCPCB | 0.465
SW4 |  | RECOVERY | SW_Push_1P1T_XKB_TS-1187A |  | Select by Customer | TS-1187A-B-A-B | XKB Connection | SMD-4P,5.1x5.1mm | -30℃~+85℃ 1.5mm 1.6N 100,000 Cycles 12V 5.1mm 5.1mm 50mA Gold No Round Button SPST Surface Mount,Vertical Without Bracket SMD-4P,5.1x5.1mm Tactile Switches ROHS | Tactile Switches | 1.Multiple lines in the BOM have been matched to the same part. Please check if the matching is correct. ; | C318884 | https://jlcpcb.com/partdetail/XKBConnection-TS_1187A_B_AB/C318884 | Basic | 25 | 25 JLCPCB | 0.465
U1 |  | RT9193-18GB | SOT-23-5 |  | Select by System | RT9193-18GB | Richtek Tech | SOT-23-5 | -40℃~+85℃@(Ta) 1 1.8V 100uVrms 300mA 300mV@(300mA) 5.5V 70dB@(100Hz) 90uA Fixed Over Current Protection Positive SOT-23-5 Voltage Regulators - Linear, Low Drop Out (LDO) Regulators ROHS | Voltage Regulators - Linear, Low Drop Out (LDO) Regulators |  | C27416 | https://jlcpcb.com/partdetail/RichtekTech-RT919318GB/C27416 | Extended | 7 | 7 JLCPCB | 0.8981
U4,U3,U2 |  | TPS564257DRLR | SOT50P160X60-6N |  | Select by System | TPS564257DRLR | Texas Instruments | SOT-563 | -40℃~+125℃@(TJ) 1 370uA 3V~17V 4A 600kHz 600mV~10V Adjustable Buck Buck Built-In Yes SOT-563 DC-DC Converters ROHS | DC-DC Converters |  | C19272233 | https://jlcpcb.com/partdetail/TexasInstruments-TPS564257DRLR/C19272233 | Extended | 15 | 15 JLCPCB | 5.1525
U6,U12,U24 |  | SY6280AAC | SOT-23-5 |  | Select by System | SY6280AAC | Silergy Corp | SOT-23-5 | -40℃~+125℃ 1 2.4V~5.5V 80mΩ Active High High Side Switch Overcurrent Protection(OCP) SOT-23-5 Power Distribution Switches ROHS | Power Distribution Switches |  | C55136 | https://jlcpcb.com/partdetail/SilergyCorp-SY6280AAC/C55136 | Extended | 17 | 17 JLCPCB | 1.3923
U7,U13 |  | FUSB302BUCX | WLCSP9_1P2X1P2_ONS |  | Select by System | FUSB302BUCX | onsemi | WLCSP-9(1.2x1.3) | -40℃~+85℃ 2.8V~5.5V Controller WLCSP-9(1.2x1.3) USB Converters ROHS | USB Converters |  | C891307 | https://jlcpcb.com/partdetail/onsemi-FUSB302BUCX/C891307 | Extended | 10 | 10 JLCPCB | 4.77
U8,U14,U10,U26,U16,U22,U15,U9,U23 |  | TPD4E02B04 | USON-10_2.5x1.0mm_P0.5mm |  | Select by System | TPD4E02B04DQAR | Texas Instruments | USON-10(1x2.5) | -40℃~+125℃ 0.33pF 10nA 17W@8/20us 2A@8/20us 3.6V 4 7.5V 8.8V Bidirectional IEC 61000-4-2 TVS USON-10(1x2.5) ESD and Surge Protection (TVS/ESD) ROHS | ESD And Surge Protection (TVS/ESD) |  | C106794 | https://jlcpcb.com/partdetail/TexasInstruments-TPD4E02B04DQAR/C106794 | Extended | 47 | 47 JLCPCB | 4.6342
U17 |  | SPIFlash | WSON-8-1EP_6x5mm_P1.27mm_EP3.4x4.3mm |  | Select by Customer | W25Q128JVPIQ | Winbond Elec | WSON-8-EP(5x6) | 100,000 Cycles 120ms@(32KB) 128Mbit 133MHz 2.7V~3.6V 20 Years SPI WSON-8-EP(5x6) NOR FLASH ROHS | NOR FLASH |  | C190862 | https://jlcpcb.com/partdetail/WinbondElec-W25Q128JVPIQ/C190862 | Extended | 5 | 5 JLCPCB | 4.875
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

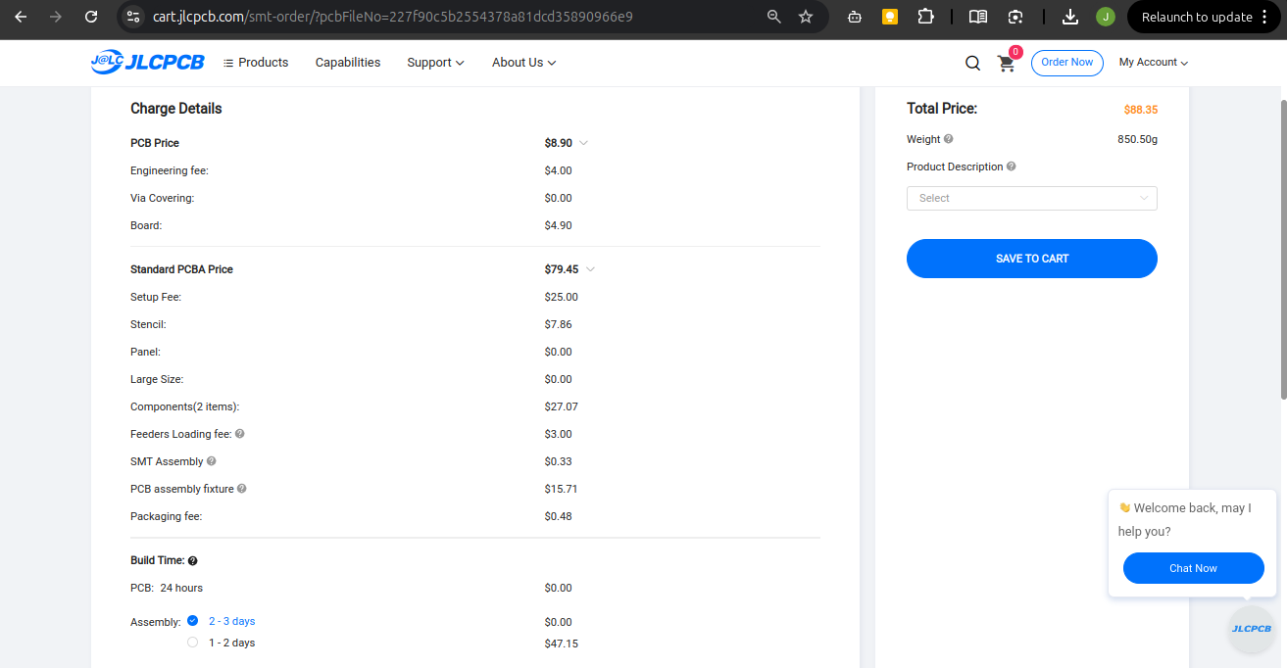
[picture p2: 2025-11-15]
PCB/BOM/Screenshot from 2025-11-15 17-23-36.png

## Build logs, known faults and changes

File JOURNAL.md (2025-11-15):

[motherboard](/user-attachments/blobs/proxy/eyJfcmFpbHMiOnsiZGF0YSI6MTE0MTAsInB1ciI6ImJsb2JfaWQifX0=--0747367de00b5cff7997b1ae485e82461773f013/motherboard.pdf)
[Pcb](/user-attachments/blobs/proxy/eyJfcmFpbHMiOnsiZGF0YSI6MTEzODUsInB1ciI6ImJsb2JfaWQifX0=--685fe88fbd5aa6a94ca59c2edd346767066ce21d/Pcb.webp)
Introduction

This project started because I wanted a motherboard that didn’t exist—something compact, powerful, and completely built around the RK3588. I’d seen development boards using this chip, but I wanted to understand the entire process of designing my own board from scratch.

I knew it wouldn’t be easy (and it wasn’t), but this journal captures how I built the project, the steps I took, and the challenges I ran into along the way.

How I Built the Project
1. Learning the RK3588 and Defining What I Wanted

Before touching any design software, I spent a lot of time reading the RK3588 documentation. Not just skimming—really digging into:

What power rails it needs

How many layers the PCB would likely require

Memory interfaces

High-speed signal rules (PCIe, USB 3.0, HDMI, etc.)

Once I had a decent understanding, I created a simple list of features I wanted my motherboard to have:

RK3588 SoC

LPDDR4x RAM

M.2 slot for NVMe storage

USB 3.0 ports

HDMI output

Ethernet

Reliable power delivery with room for thermal dissipation

This list gave me direction so I didn’t design blindly.

2. Creating the Schematic (The Big Brain of the Board)

The schematic phase was the most mentally demanding part. Using KiCad, I slowly pieced together:

Power regulation circuits

DRAM connections (this part required extreme attention to detail)

USB, HDMI, Ethernet, and PCIe blocks

Clocks and oscillators

All the required supporting resistors, capacitors, and inductors

I constantly bounced between KiCad and the RK3588 datasheet, double-checking I hadn’t missed a requirement.

One of the trickiest parts was ensuring the power rails were correct. The RK3588 uses several different voltages, and some rails require very low noise. Designing a stable power tree took more time than expected.

3. Starting the PCB Layout (Where the Board Became Real)

Moving from schematic to PCB layout felt like going from planning to building the house.

I began with the RK3588 footprint in the center. It’s a massive BGA with a huge number of balls, so the breakout itself was a small project.

Some challenges I faced during layout:

Routing high-speed signals without skew

Getting the DDR lanes length-matched

Ensuring all power planes were solid and continuous

Keeping noisy power sections away from sensitive ones

Making room for the M.2 slot and ports without causing routing nightmares

Every time I thought I was done, I would realize something needed to be moved or rerouted.

It was like solving a puzzle that changed shape every time you touched it.

4. Thermal and Electrical Considerations

Because the RK3588 can run hot, I needed to think seriously about cooling.

I added:

Thermal vias under the SoC

Room for a heatsink or a small fan

Wider copper pours for power traces to reduce heat buildup

On the electrical side, I simulated a few critical traces to check for potential signal issues. It wasn’t perfect, but it gave me confidence the board wouldn't fail immediately.

5. Ordering the Prototype

When the board layout finally looked right (or right enough), I generated the Gerber files and sent them to a PCB manufacturer.

While waiting for the boards, I ordered all the components. Seeing boxes of tiny parts arrive made the project feel very real.

When the PCB finally arrived, holding it in my hands felt surreal—like I had built something that should only come from a real hardware company.

6. Assembly and First Power-On

Assembly was nerve-wracking. The RK3588 is a huge BGA, so I used a reflow hot plate. Watching the solder paste melt and hoping everything aligned felt like defusing a bomb.

Before powering it up, I checked every power rail with a multimeter.

The first power-on didn’t work.
Nothing exploded (good), but nothing booted (not ideal).

After several hours of probing the board, I found one power rail wasn’t actually reaching the SoC. A single trace error. Fixing it felt like performing surgery, but afterward…

The board powered on.
Seeing that first boot log made the whole project worth it.

7. Debugging and Getting Everything Working

Even after it powered on, a few things didn’t work:

HDMI had signal issues

One USB port wasn’t recognized

Ethernet was unstable

Each problem taught me something new about signal routing and grounding. Bit by bit, I patched issues until everything behaved as expected.

8. Finalizing and Documenting the Design

Once the prototype was stable, I cleaned up:

The PCB layout

The component list

The routing around sensitive lanes
motherboard-B_Courtyard
motherboard-B_Silkscreenmotherboard-B_Adhesivemotherboard-B_Pastemotherboard-B_Mask
motherboard-F_Fabmotherboard-B_Cu
motherboard-F_Pastemotherboard-F_Maskmotherboard-Edge_Cutsmotherboard-F_Courtyard
motherboard-F_Silkscreenmotherboard-F_Adhesive
motherboard-In3_Cumotherboard-In1_Cu
motherboard-In4_Cu
motherboard-User_Commentsmotherboard-F_Cumotherboard-In2_Cu
motherboard-User_Drawingsmotherboard-User_1motherboard-Margin
motherboard-User_Eco2motherboard-User_Eco1

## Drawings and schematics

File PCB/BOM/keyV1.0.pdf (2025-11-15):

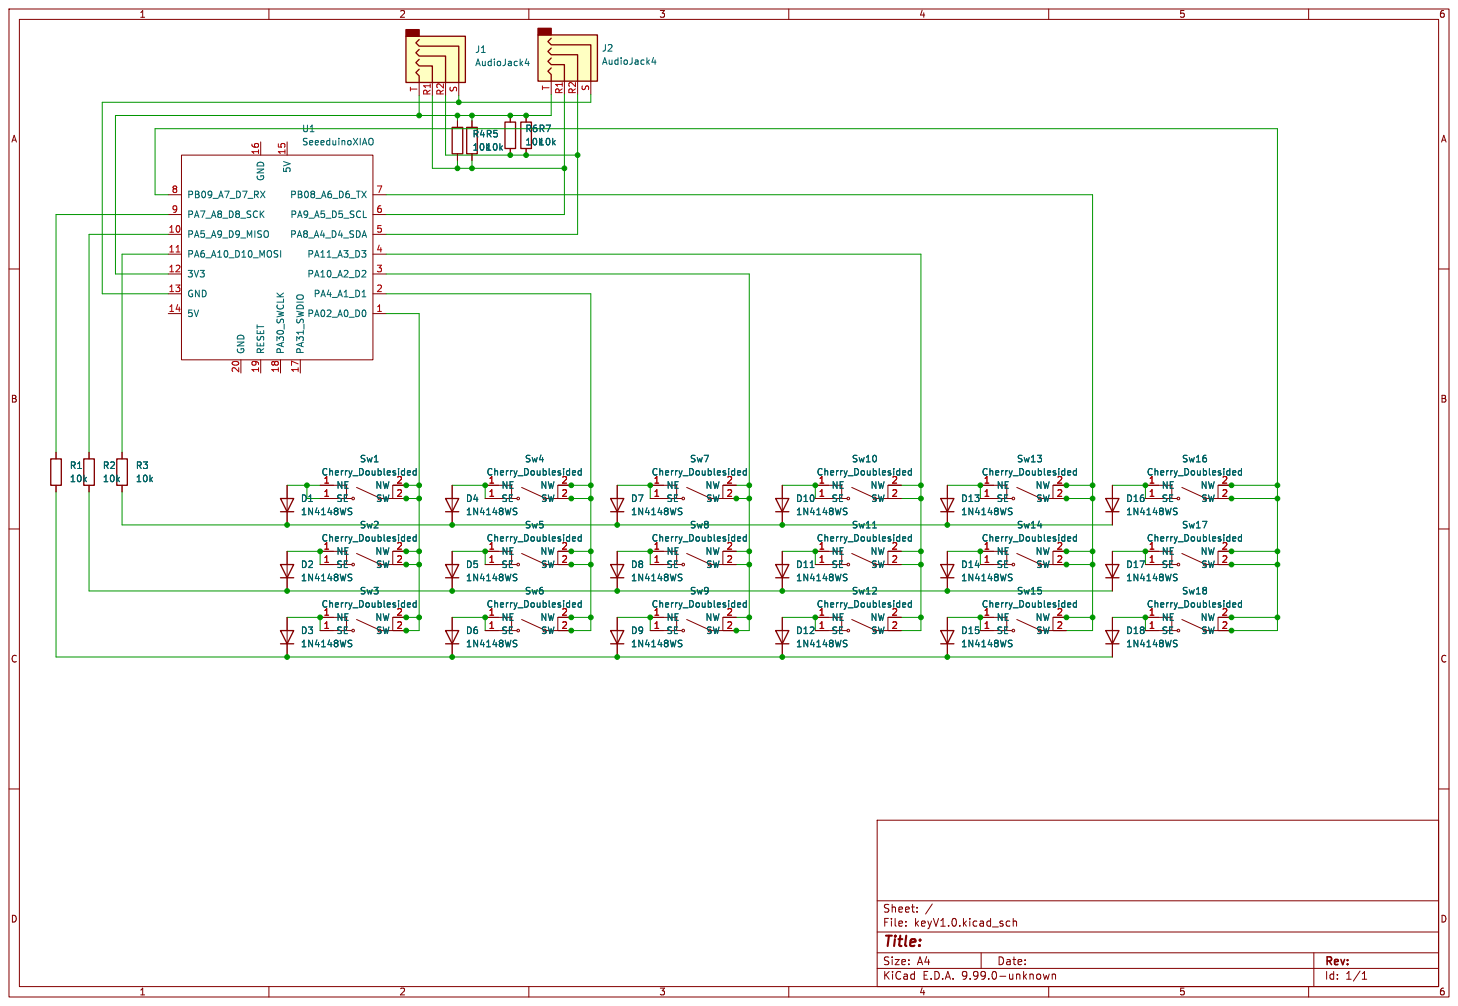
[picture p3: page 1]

Id: 1/1 Title: File: keyV1.0.kicad_sch Sheet: / D11

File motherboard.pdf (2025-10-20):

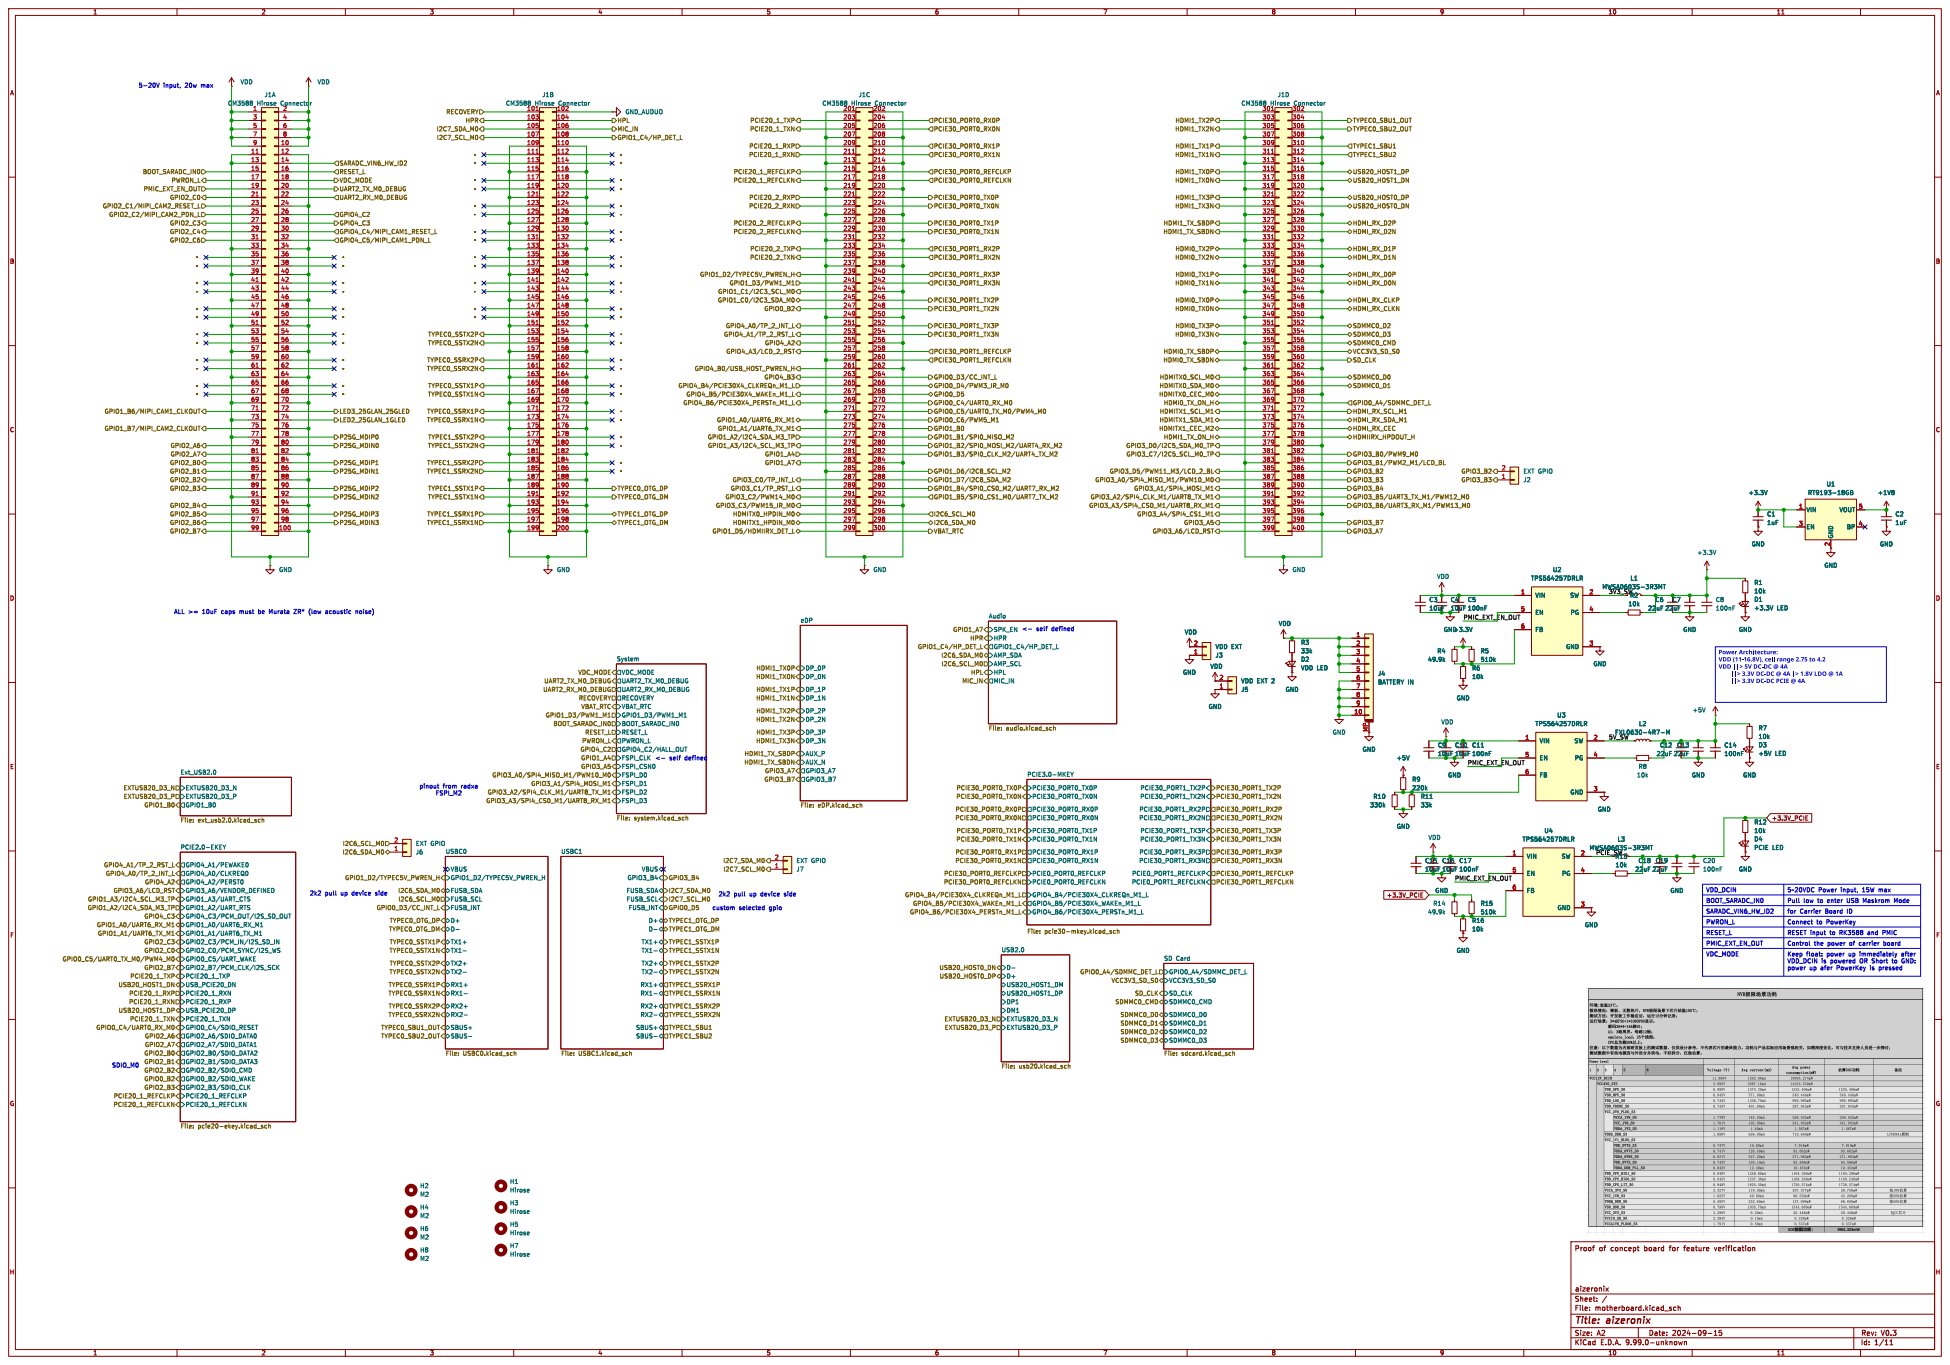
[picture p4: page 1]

Power Architecture: VDD (11-16.8V), cell range 2.75 to 4.2 VDD ||> 5V DC-DC@4A
+5V GND

SDMMC0_D1 SD Card File: sdcard.kicad_sch EXTUSB20_D3_N

2k2 pull up device side

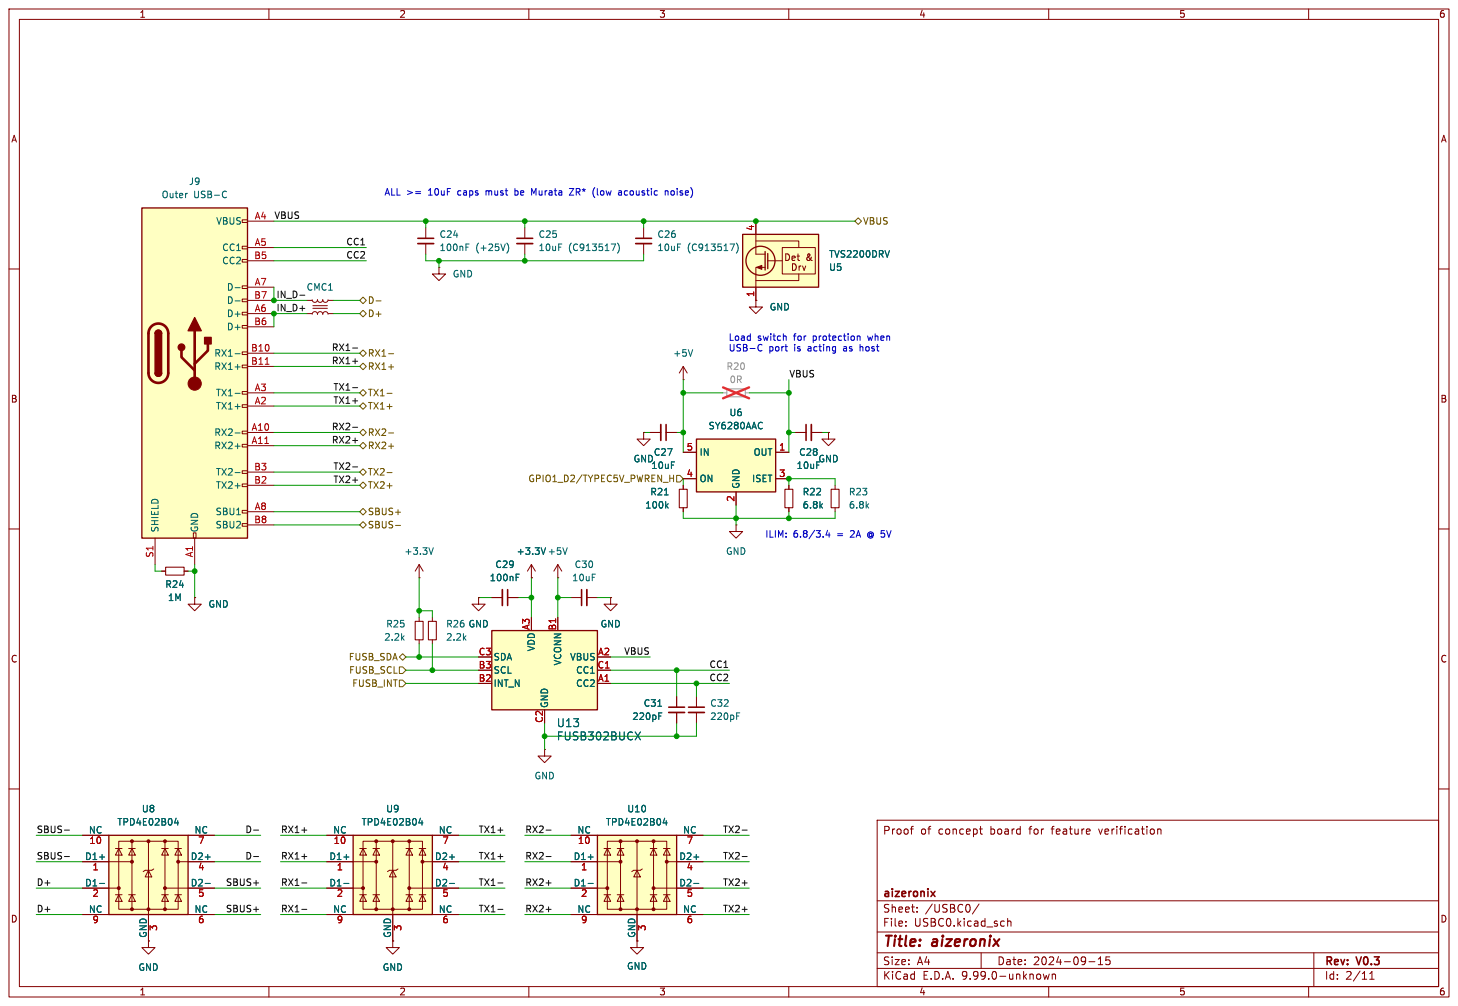
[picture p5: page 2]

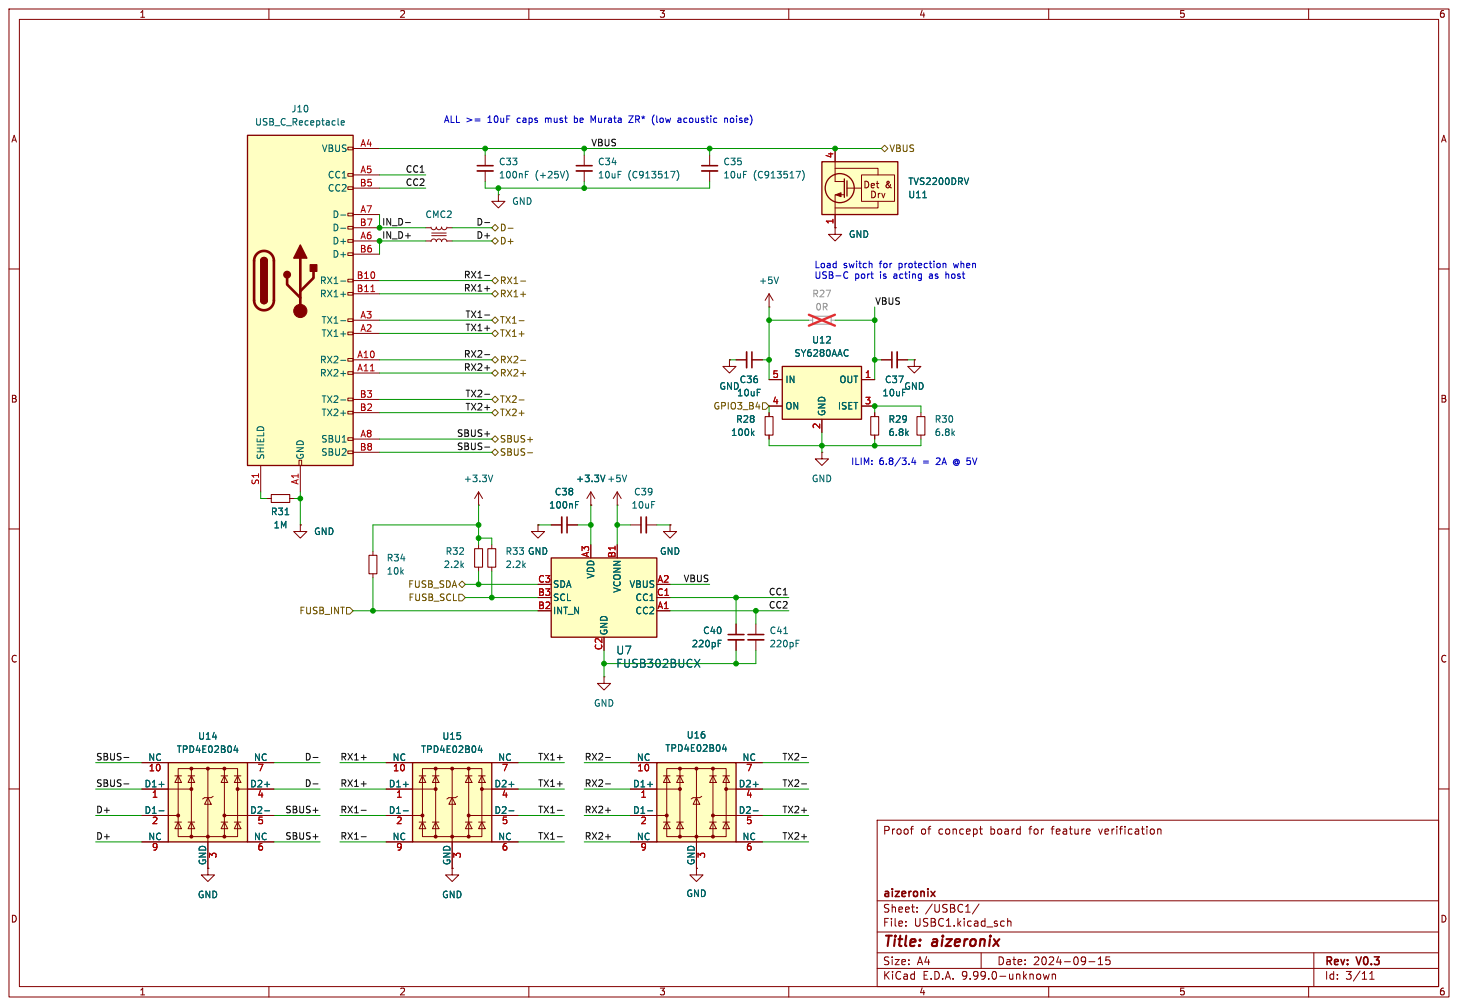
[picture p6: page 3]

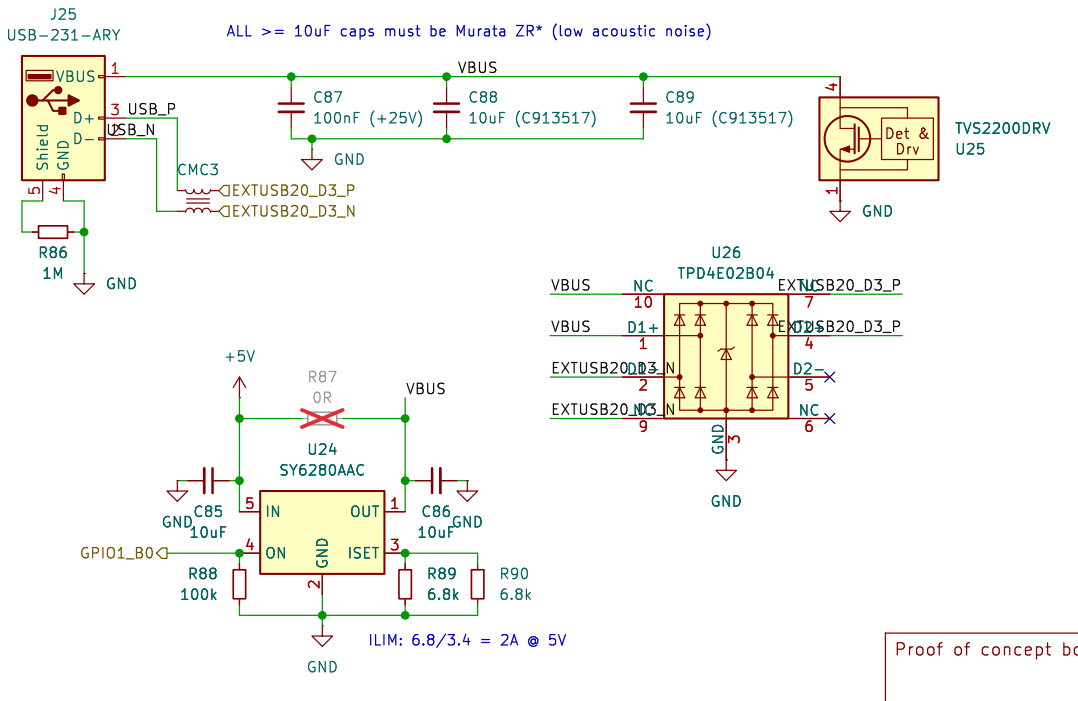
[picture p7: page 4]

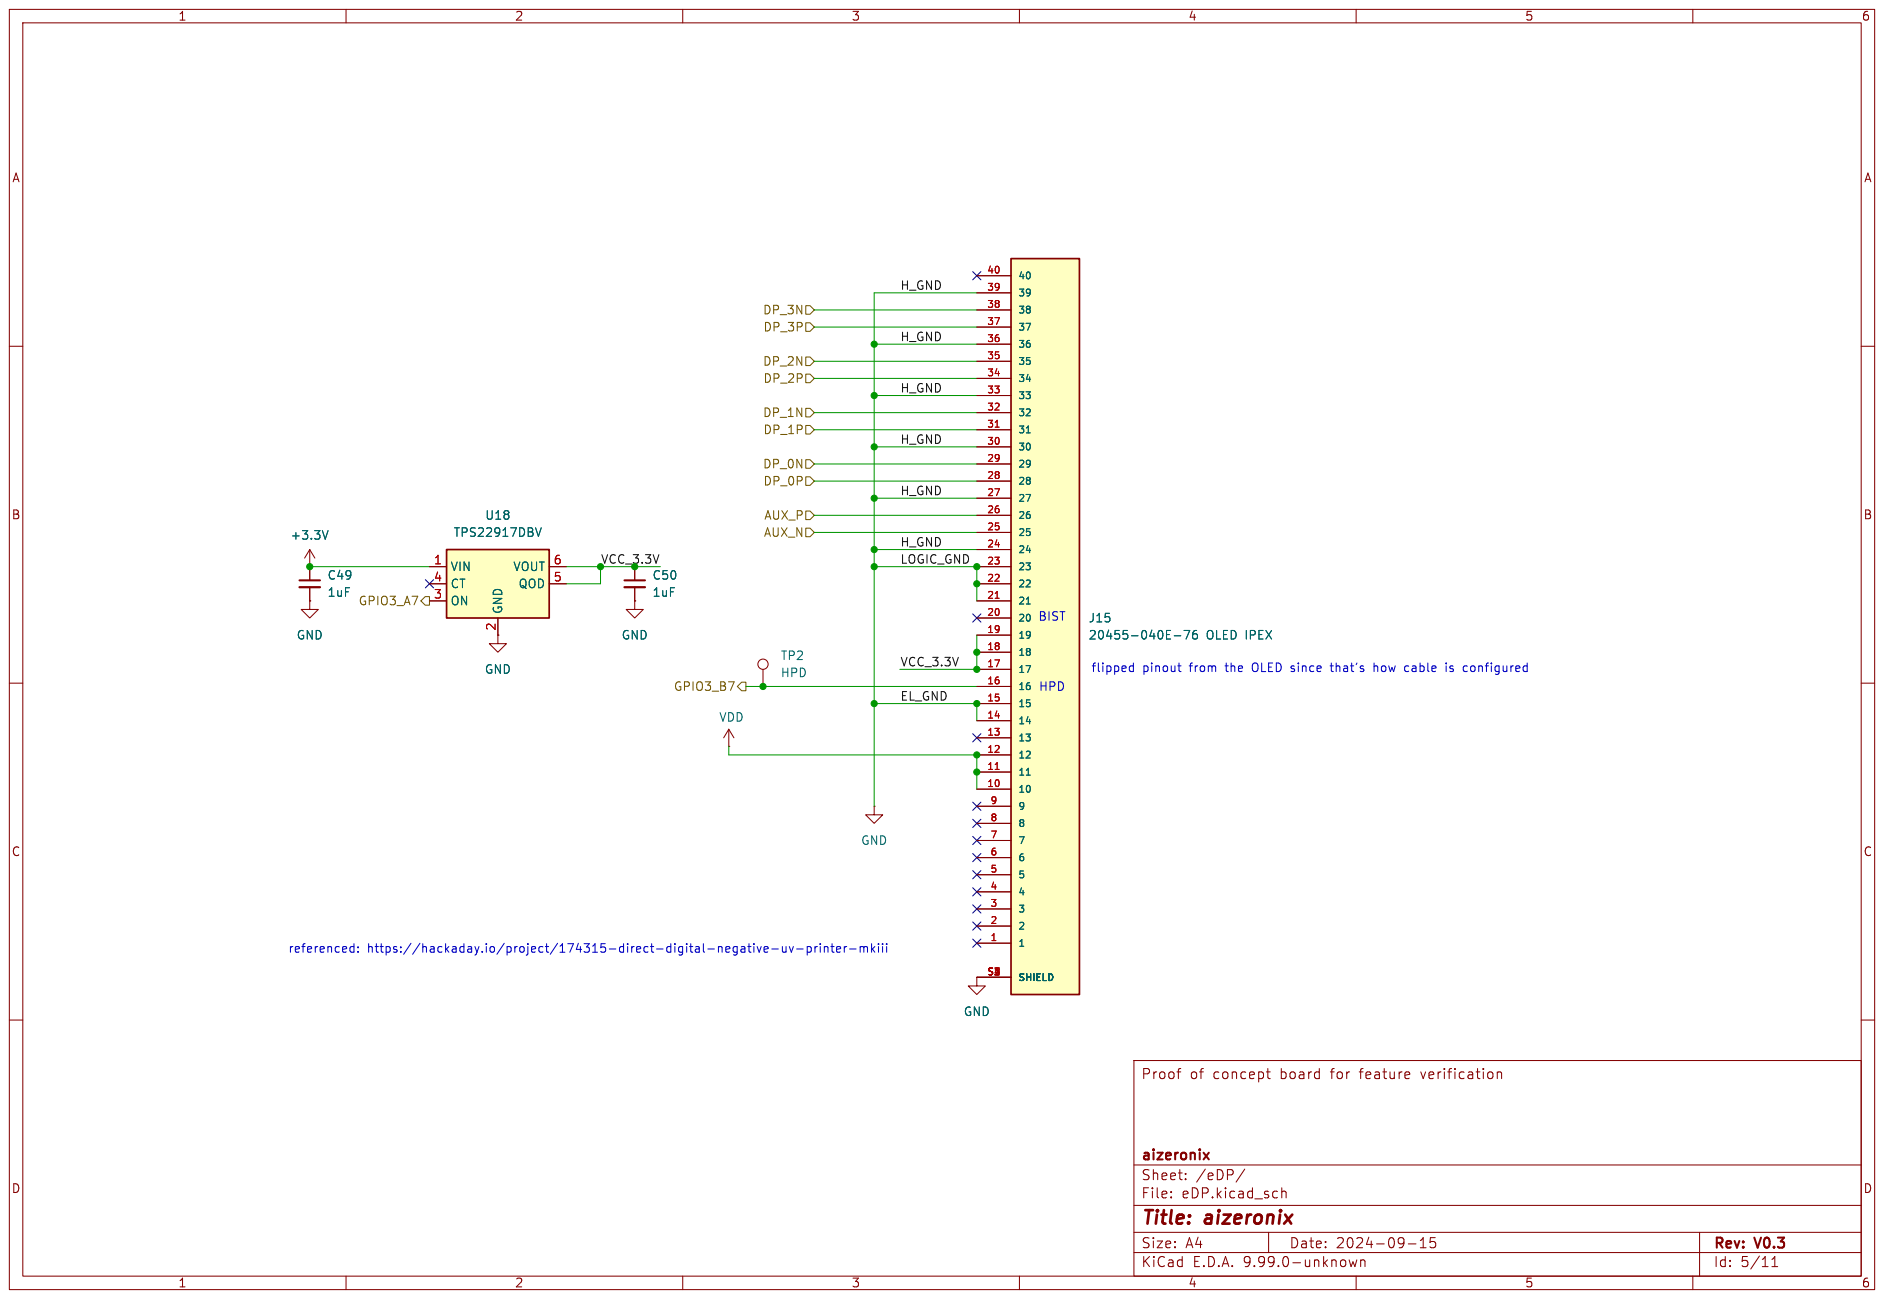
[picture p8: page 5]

2 VOUT 6 QOD 5 U18 TPS22917DBV GND GND

2 VOUT 6 QOD 5 GND GND

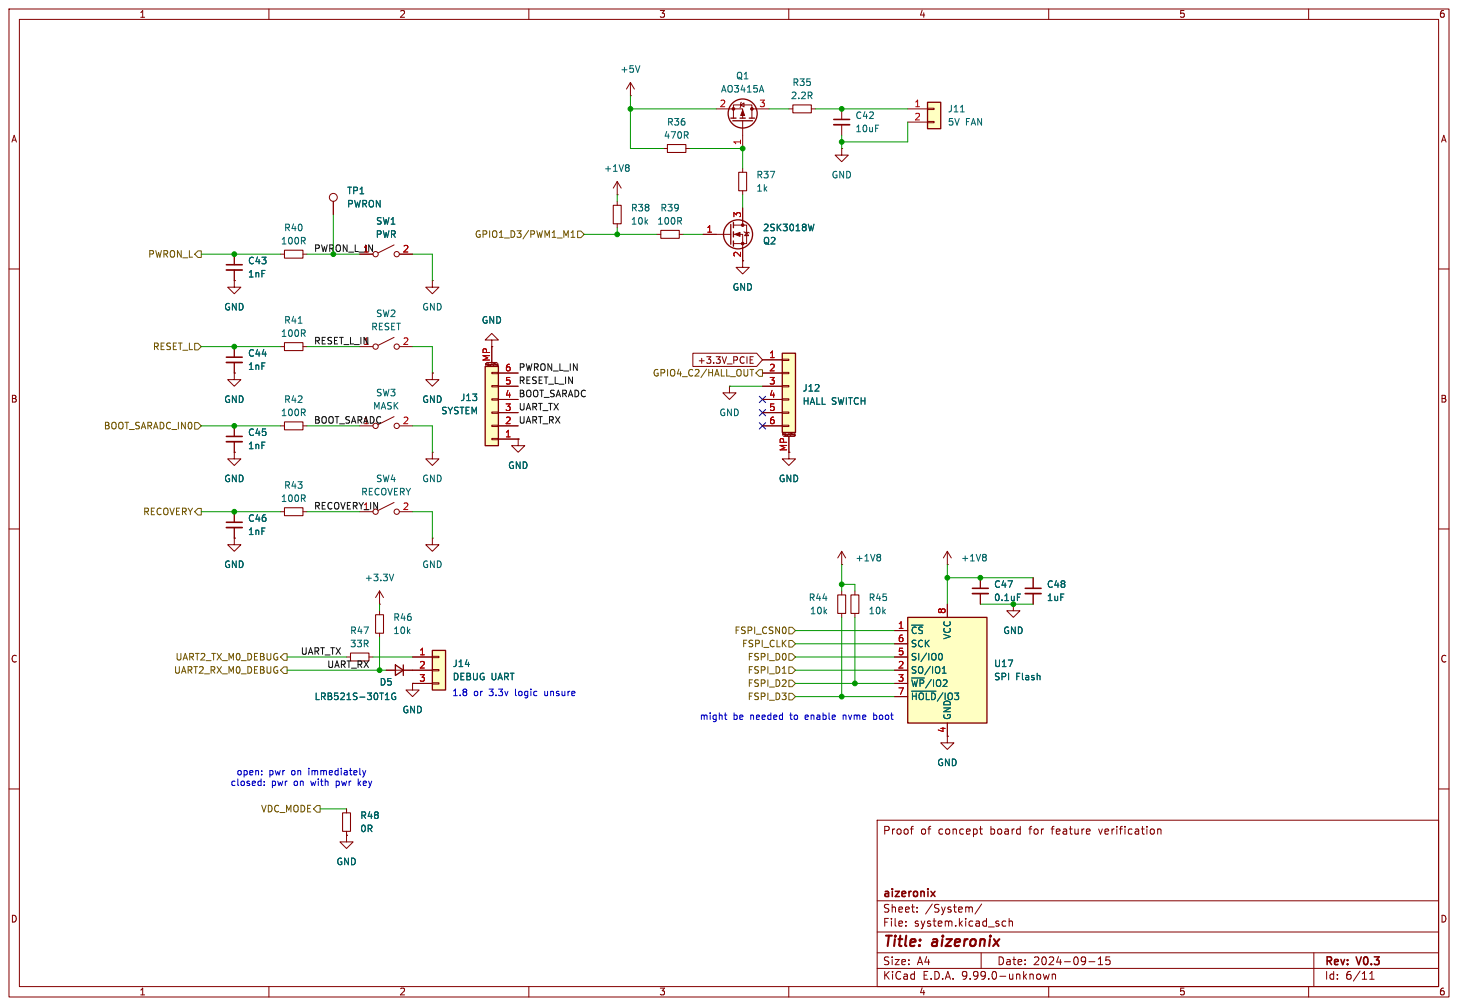
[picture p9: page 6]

closed: pwr on with pwr key GND

4 U17 SPI Flash GND GND

J12 HALL SWITCH GND GND

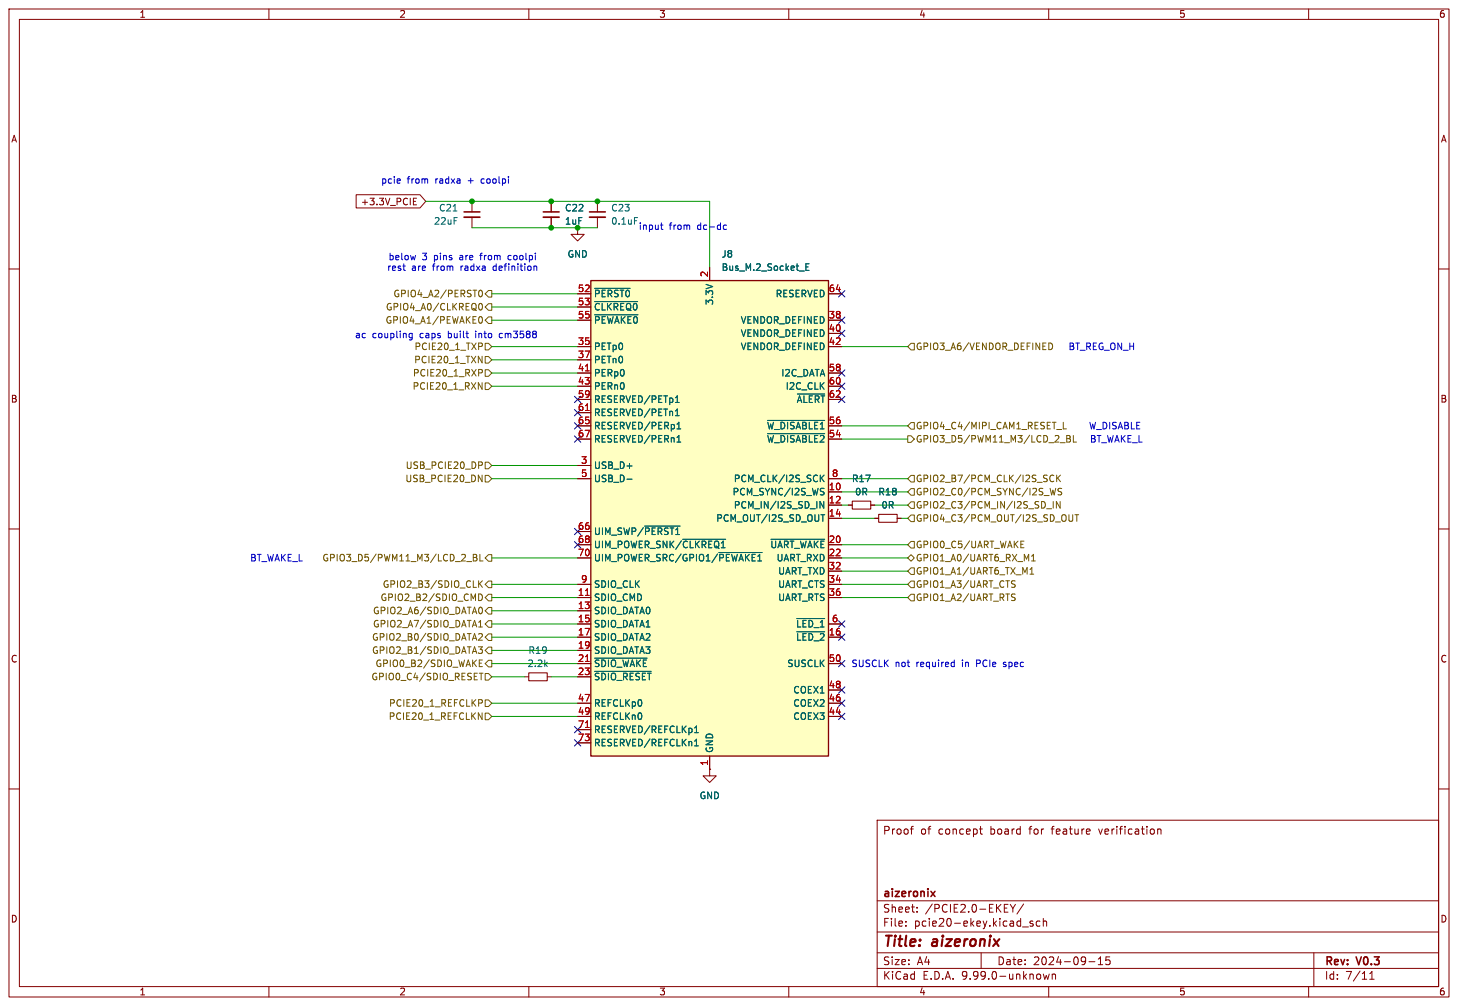
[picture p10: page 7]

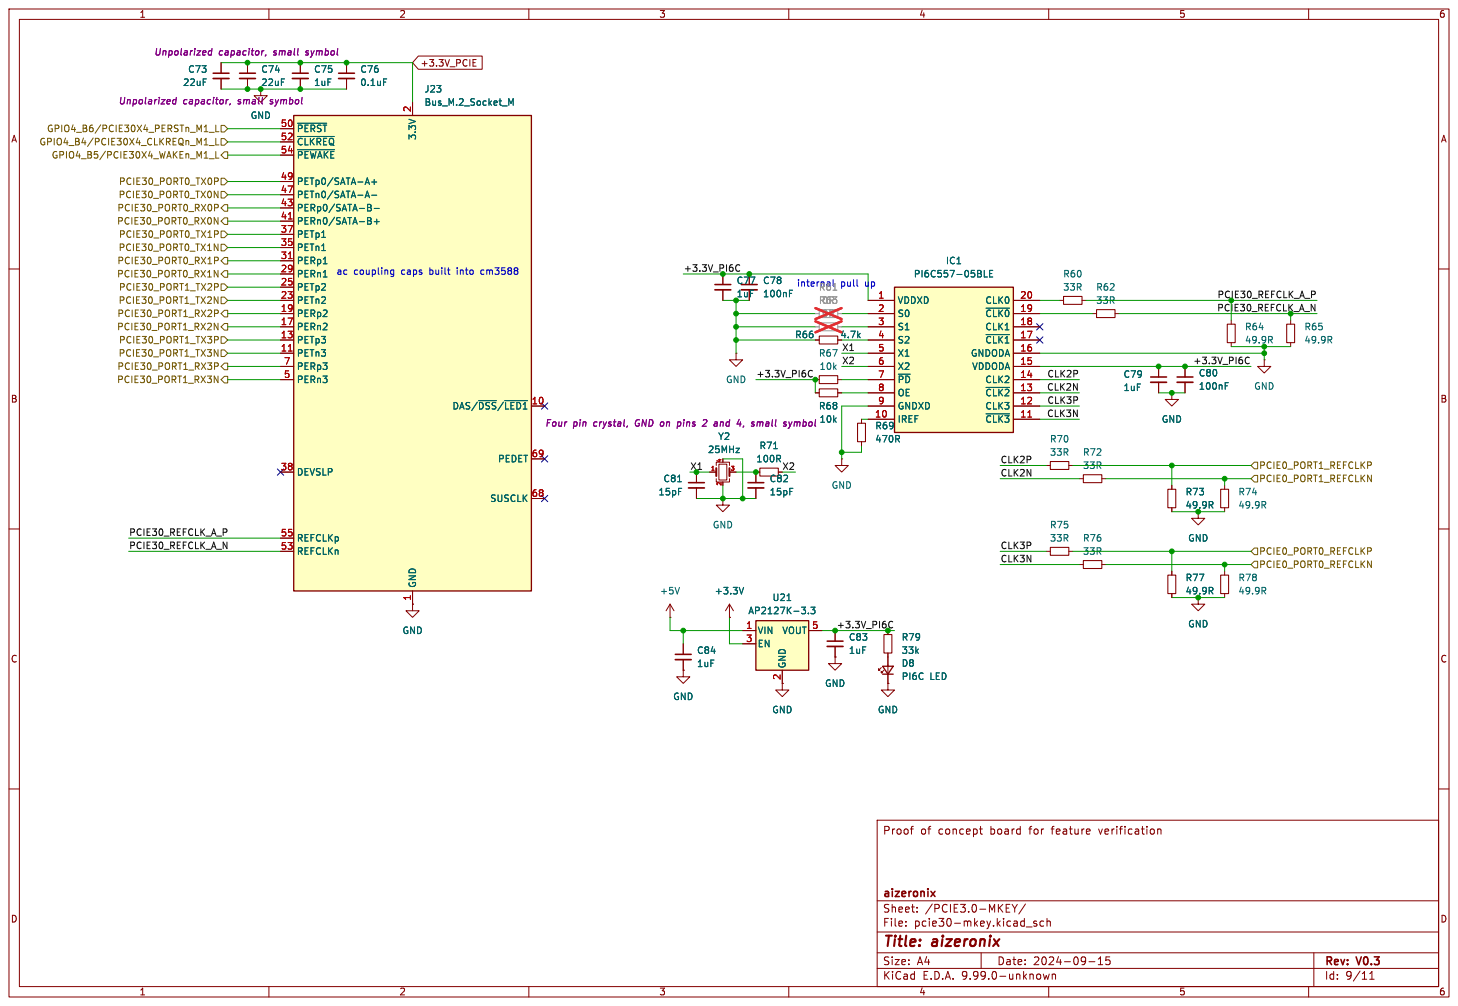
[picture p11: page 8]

1 DAS/~{DSS}/~{LED1} 10 PEDET 69 SUSCLK 68 GND

1 DAS/~{DSS}/~{LED1} 10 PEDET 69 SUSCLK 68

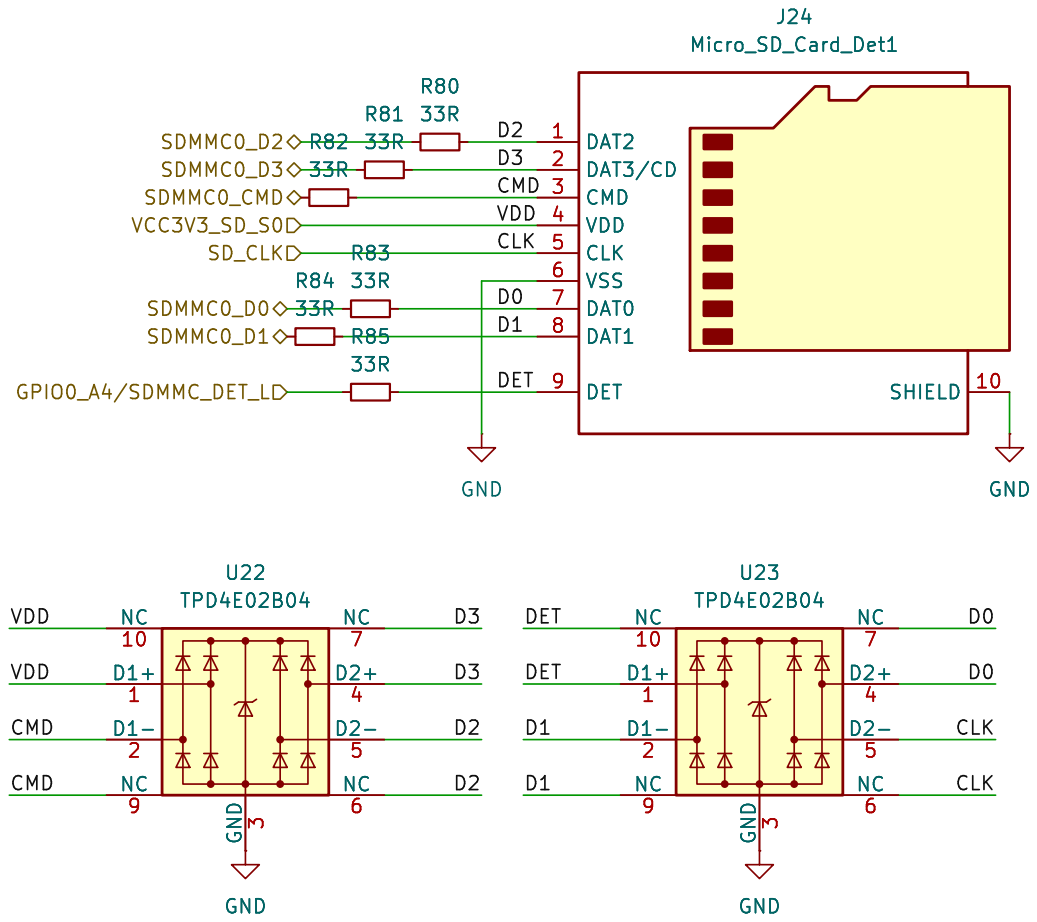
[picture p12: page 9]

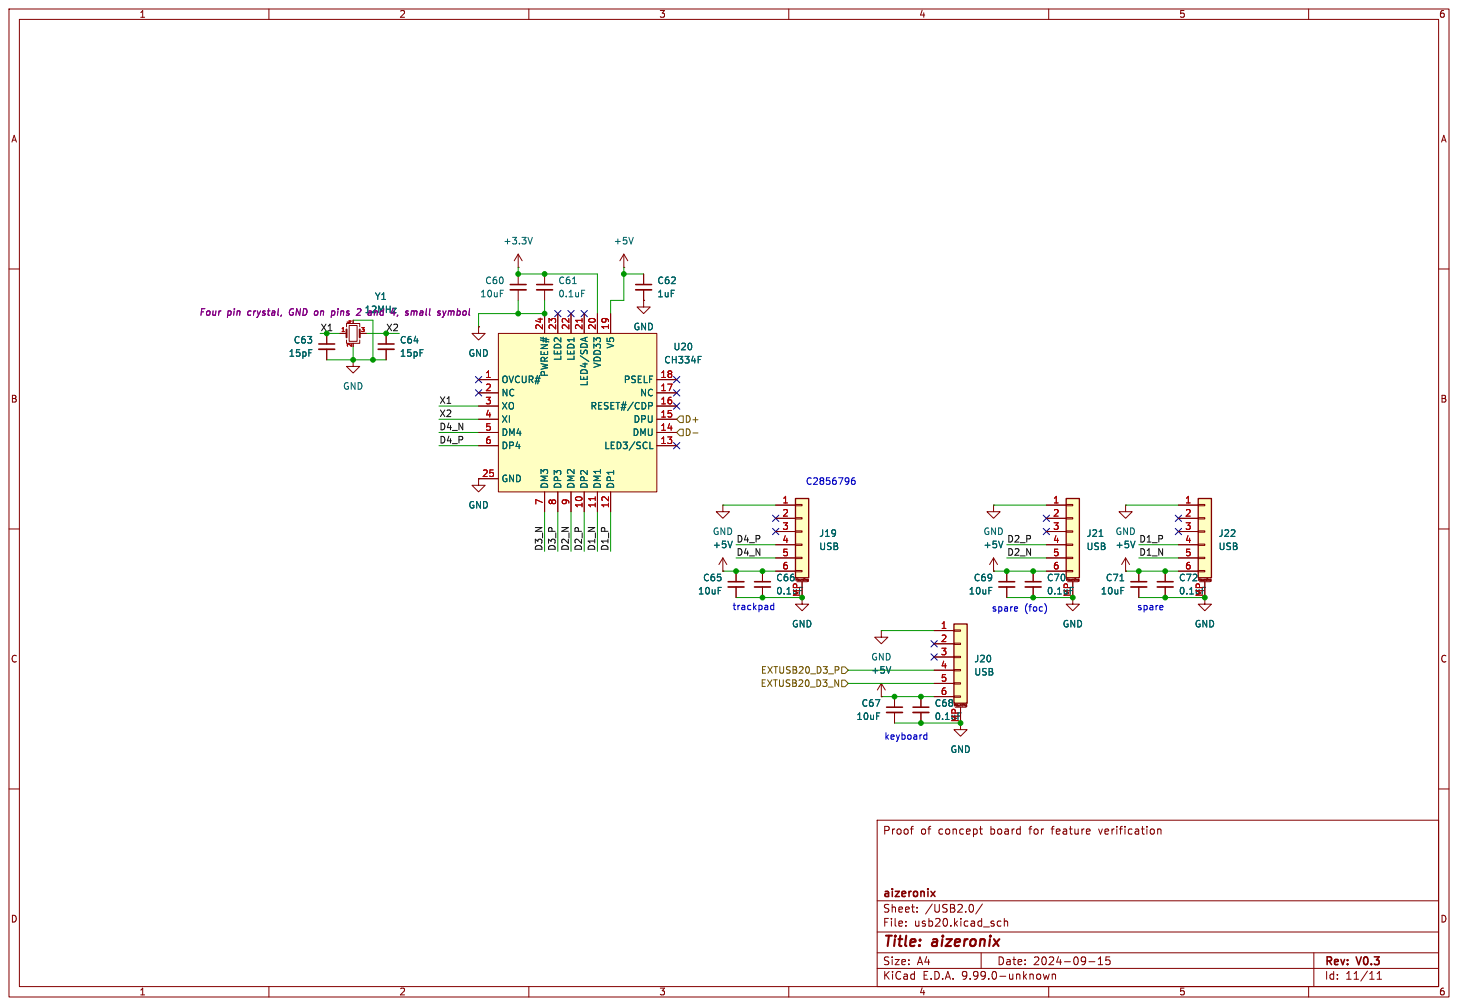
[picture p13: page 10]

9 LED4/SDA 21 DP2 10 VDD33 20 DM1 11 V5 19 DP1 12 PSELF 18 NC 17 RESET#/CDP 16 DPU 15 DMU 14

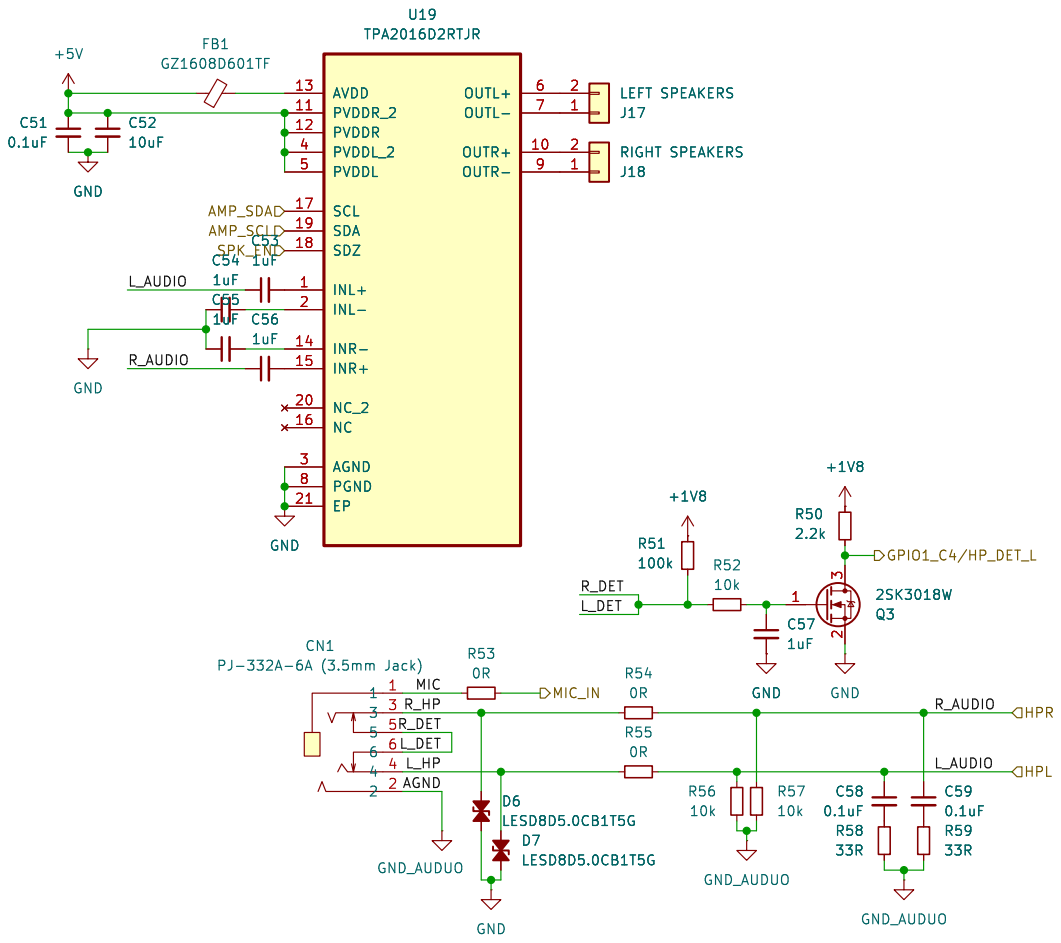
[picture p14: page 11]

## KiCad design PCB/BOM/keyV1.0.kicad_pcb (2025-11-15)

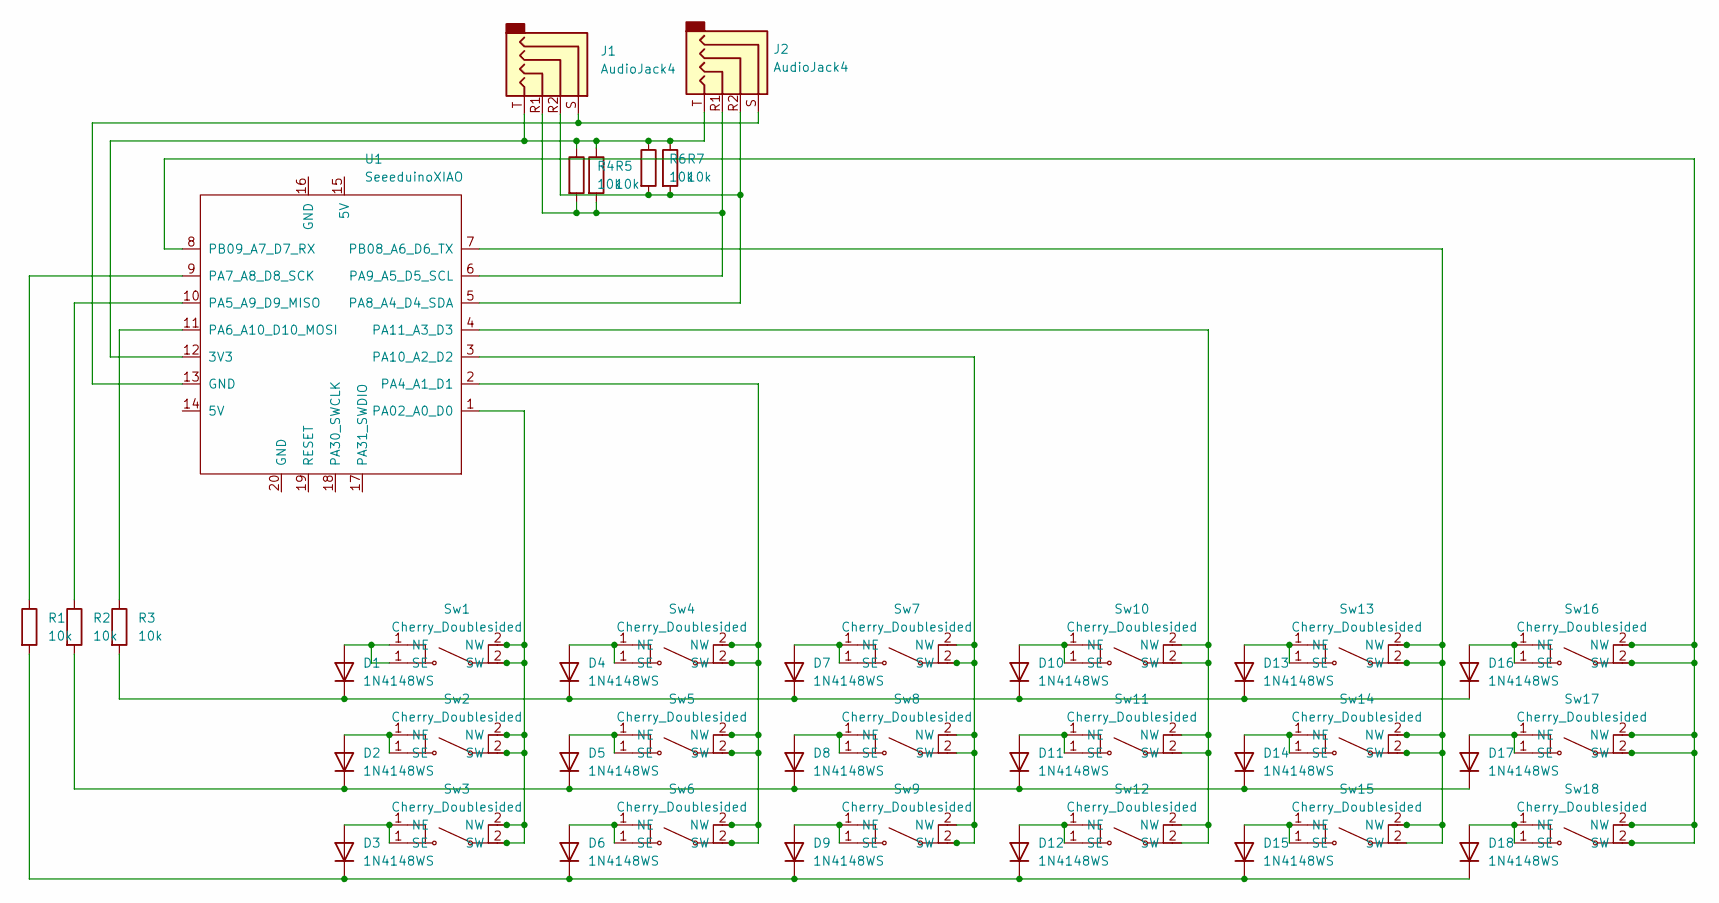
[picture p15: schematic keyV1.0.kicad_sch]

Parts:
D1, D2, D3, D4, D5, D6, D7, D8, D9, D10, D11, D12, D13, D14, D15, D16, D17, D18: 1N4148WS; D_SOD-323_HandSoldering
J1, J2: AudioJack4; Jack_3.5mm_PJ320D_Horizontal
R1, R2, R3, R4, R5, R6, R7: 10k; R_0805_2012Metric_Pad1.20x1.40mm_HandSolder
Sw1, Sw2, Sw3, Sw4, Sw5, Sw6, Sw7, Sw8, Sw9, Sw10, Sw11, Sw12, Sw13, Sw14, Sw15, Sw16, Sw17, Sw18: Cherry_Doublesided; SW_MX_reversible
U1: SeeeduinoXIAO; Seeeduino XIAO-MOUDLE14P-2.54-21X17.8MM

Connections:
unnamed: D1.1 (K), D4.1 (K), D7.1 (K), D10.1 (K), D13.1 (K), D16.1 (K), R3.2
unnamed: D1.2 (A), Sw1.1 (NE)
unnamed: D2.2 (A), Sw2.1 (NE)
unnamed: D3.2 (A), Sw3.1 (NE)
unnamed: D4.2 (A), Sw4.1 (NE)
unnamed: D5.2 (A), Sw5.1 (NE)
unnamed: D6.2 (A), Sw6.1 (NE)
unnamed: D7.2 (A), Sw7.1 (NE)
unnamed: D8.2 (A), Sw8.1 (NE)
unnamed: D9.2 (A), Sw9.1 (NE)
unnamed: D10.2 (A), Sw10.1 (NE)
unnamed: D2.1 (K), D5.1 (K), D8.1 (K), D11.1 (K), D14.1 (K), D17.1 (K), R2.2
unnamed: D11.2 (A), Sw11.1 (NE)
unnamed: D3.1 (K), D6.1 (K), D9.1 (K), D12.1 (K), D15.1 (K), D18.1 (K), R1.2
unnamed: D12.2 (A), Sw12.1 (NE)
unnamed: D13.2 (A), Sw13.1 (NE)
unnamed: D14.2 (A), Sw14.1 (NE)
unnamed: D16.2 (A), Sw16.1 (NE)
unnamed: D17.2 (A), Sw17.1 (NE)
unnamed: D18.2 (A), Sw18.1 (NE)
unnamed: J1.R1, J2.R1, R4.2, R5.2, U1.6 (PA9_A5_D5_SCL)
unnamed: J1.R2, J2.R2, R6.2, R7.2, U1.5 (PA8_A4_D4_SDA)
unnamed: J1.S, J2.S, U1.13 (GND)
unnamed: J1.T, J2.T, R4.1, R5.1, R6.1, R7.1, U1.12 (3V3)
unnamed: R1.1, U1.9 (PA7_A8_D8_SCK)
unnamed: R2.1, U1.10 (PA5_A9_D9_MISO)
unnamed: R3.1, U1.11 (PA6_A10_D10_MOSI)
unnamed: Sw1.2 (NW), Sw2.2 (NW), Sw3.2 (NW), U1.1 (PA02_A0_D0)
unnamed: Sw4.2 (SW), Sw5.2 (SW), Sw6.2 (NW), U1.2 (PA4_A1_D1)
unnamed: Sw7.2 (NW), Sw8.2 (NW), Sw9.2 (NW), U1.3 (PA10_A2_D2)
unnamed: Sw10.2 (NW), Sw11.2 (NW), Sw12.2 (NW), U1.4 (PA11_A3_D3)
unnamed: D15.2 (A), Sw15.1 (NE)
unnamed: Sw13.2 (SW), Sw14.2 (SW), Sw15.2 (SW), U1.7 (PB08_A6_D6_TX)
unnamed: Sw16.2 (SW), Sw17.2 (NW), Sw18.2 (NW), U1.8 (PB09_A7_D7_RX)

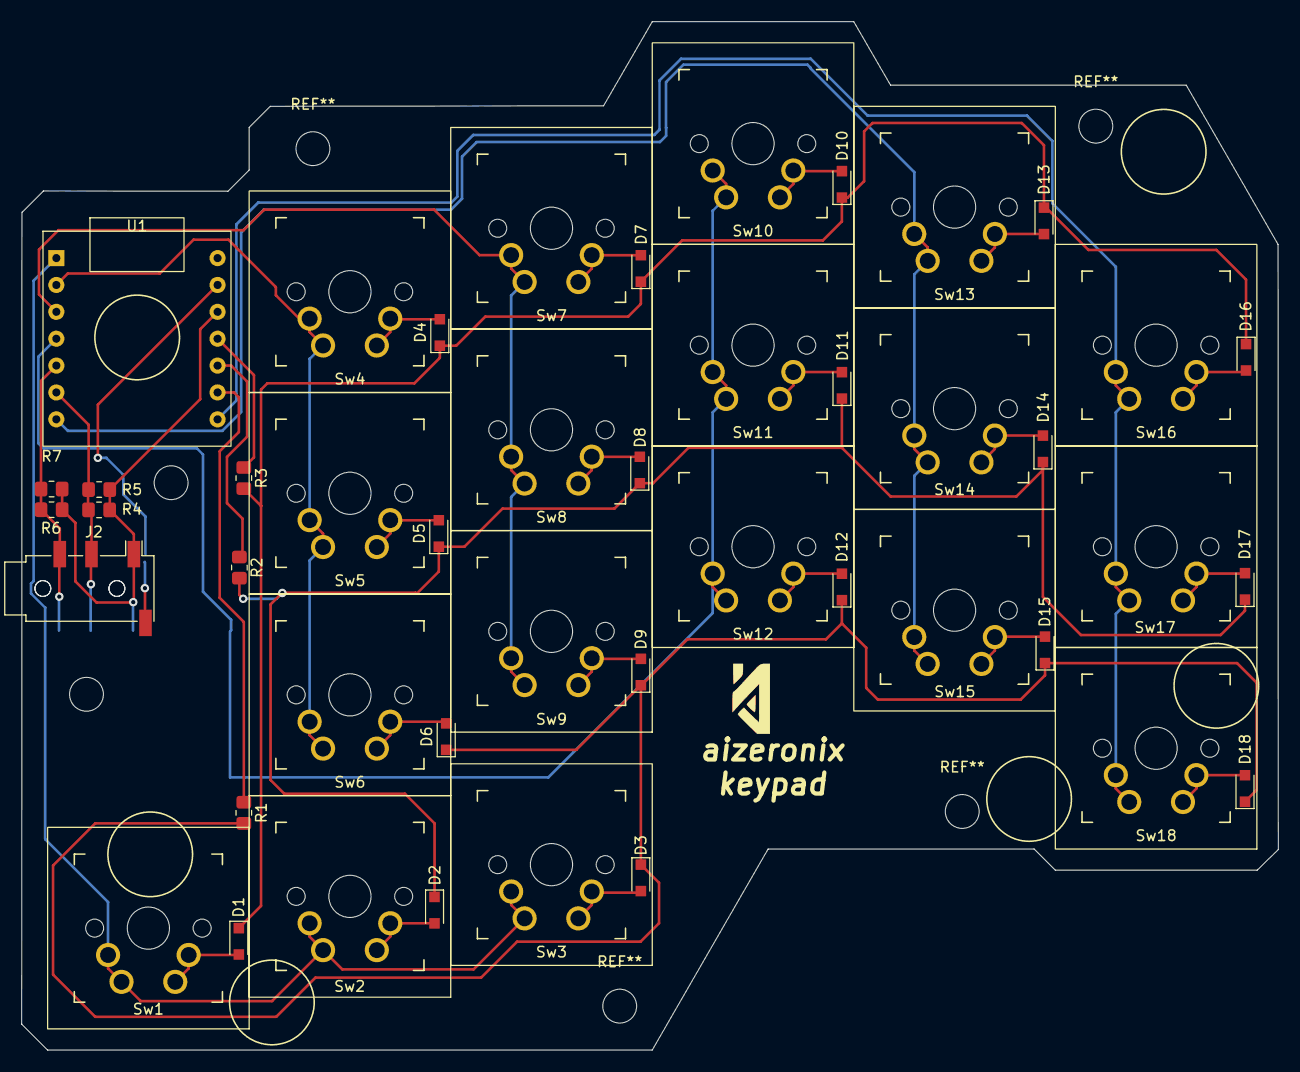
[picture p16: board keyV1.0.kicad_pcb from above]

Board: 2 copper layers, 118.8 x 97.2 mm, 47 parts (1 on the bottom side), 34 nets.

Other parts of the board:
_: LOGO; aizeronix

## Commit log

2025-10-20 Update BOM.csv with new components and corrections
    Added new components and updated existing entries in the BOM.
    [BOM.csv]
2025-10-20 Update BOM.csv with new and modified components
    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
    [BOM.csv]
2025-10-20 Update BOM.csv to include pricing information
    Added unit price and total price columns to BOM.
    [BOM.csv]
2025-11-13 Update README with project objectives
    Expanded project objectives to include schematic design, PCB layout, interface integration, power management, and testing.
